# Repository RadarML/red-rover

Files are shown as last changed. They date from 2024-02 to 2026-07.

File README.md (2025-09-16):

# Red Rover: A Multimodal mmWave Radar Spectrum Ecosystem





bear-ified (https://beartype.readthedocs.io)

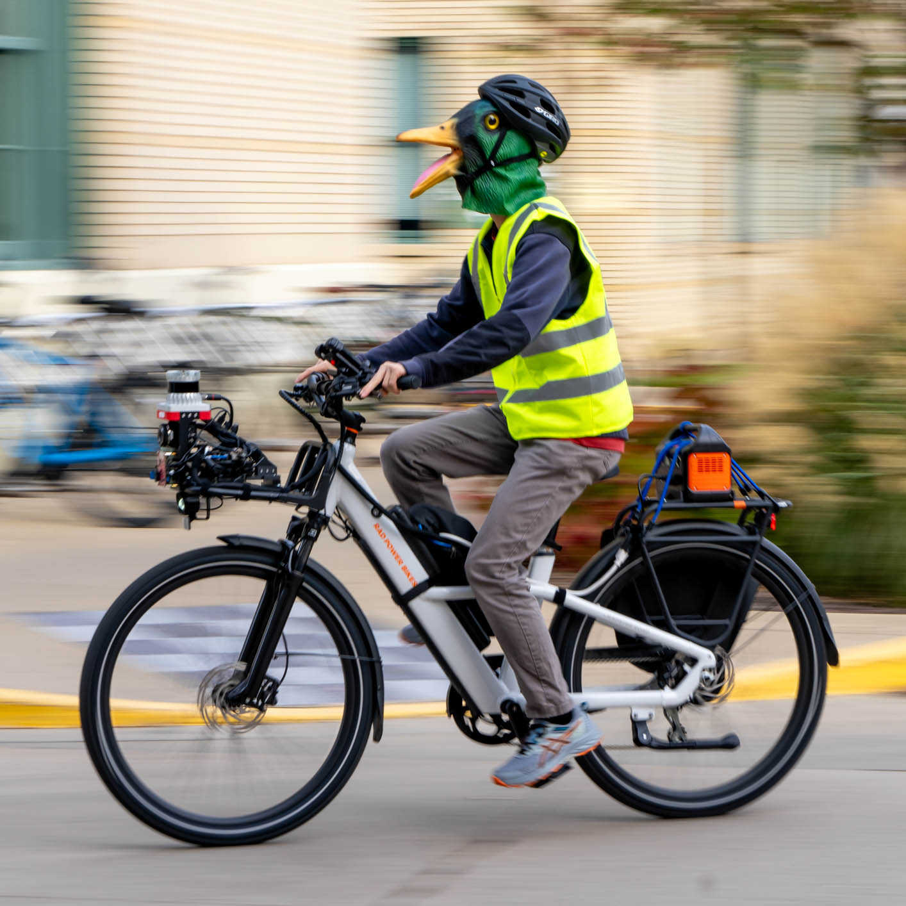
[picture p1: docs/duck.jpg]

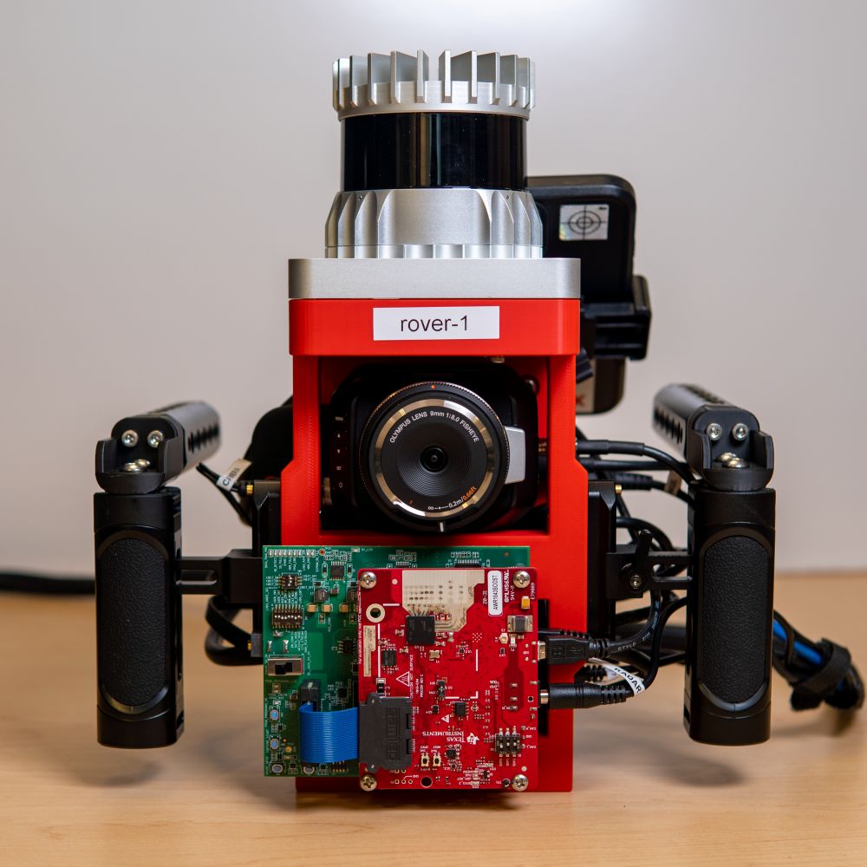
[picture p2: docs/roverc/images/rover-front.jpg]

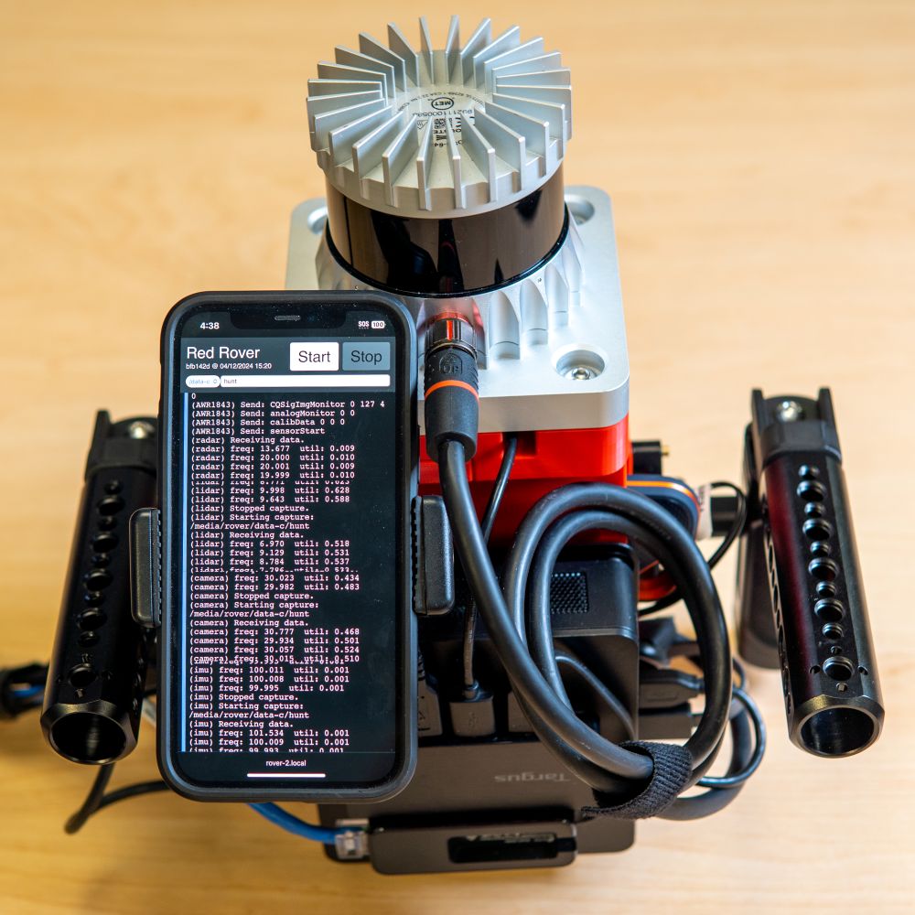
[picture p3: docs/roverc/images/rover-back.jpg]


The **red rover** project is an end-to-end system for collecting, loading, and processing mmWave radar time signal data along with lidar and camera data designed for both [DART](https://wiselabcmu.github.io/dart/)-style reconstruction and [GRT](https://wiselabcmu.github.io/grt/)-style deep learning.

> [!TIP]
> While packaged together as a mono-repo, each module is designed to be able to be installed and used separately. See each module's documentation for requirements and setup instructions.

See our [documentation site](https://radarml.github.io/red-rover/) for more details!

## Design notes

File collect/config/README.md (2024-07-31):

Current configurations (output of `./env/bin/python config/summary.py`):

```
dart.yaml         // DART, indoor
-------------------------------------------
Antenna       2tx x 4rx
Range         4.4cm   x 128 (rmax=5.59m)
Roppler       1.9cm/s x 128 (dmax=1.21m/s)
Throughput    42mbps / 701mbps
Duty cycle    99.8%
Excess ramp   2.100us
```

```
radarhd-b.yaml    // RadarHD, bike-mounted
-------------------------------------------
Antenna       3tx x 4rx
Range         17.5cm   x 256 (rmax=44.74m)
Roppler       23.4cm/s x  64 (dmax=7.49m/s)
Throughput    126mbps / 701mbps
Duty cycle    16.5%
Excess ramp   2.700us
```

```
radarhd-i.yaml    // RadarHD, indoor
-------------------------------------------
Antenna       3tx x 4rx
Range         4.4cm   x 256 (rmax=11.18m)
Roppler       3.8cm/s x  64 (dmax=1.22m/s)
Throughput    126mbps / 701mbps
Duty cycle    99.5%
Excess ramp   2.100us
```

```
radarhd-o.yaml    // RadarHD, outdoor
-------------------------------------------
Antenna       3tx x 4rx
Range         8.7cm   x 256 (rmax=22.37m)
Roppler       3.9cm/s x  64 (dmax=1.24m/s)
Throughput    126mbps / 701mbps
Duty cycle    99.5%
Excess ramp   2.100us
```

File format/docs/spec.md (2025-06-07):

# Data Format Specifications

!!! abstract "TL;DR"

    The `roverd` data format is an extremely simple, flexible, and extendable data storage format based on simple binary containers.

## Design Goals

The rover dataset format, `roverd` is designed to handle data collection and storage for concurrent sensor streams with a fixed dimension, such as camera, lidar, or radar data.

### Seamless Collection & Training

!!! success "Appendable"

    The data format should be easy to append new observations to.

    *By writing files in a simple binary format in a time-synchronous way within each sensor stream, appending data is trivial -- just append data to the file; no metadata updates are required.*

!!! success "Fail-safe"

    If the data collection program or device were to fail during data collection, the amount of lost or corrupted data should be minimized.

    *Since data is simply appended without any summary metadata which needs to be committed when the file is closed, program or device crashes only lose any data which is currently buffered.*

!!! success "Suitable for ML"

    The storage format should facilitate common machine learning access patterns (e.g., random access), so that collected data can immediately be used for training.

    *All data types are designed to facilitate random access right out-of-the-box, without any mandatory preprocessing.*

### Lightweight & Hackable 

!!! success "Readable with common tools"

    The collected data and metadata should be readable with off-the-shelf software (e.g. what ships with a stock linux, windows, or Mac OS distribution) to the greatest extent possible.

    *Data is organized using the native file system, and can be browsed using any file manager. Metadata files are simple `.json` or `.yaml` files, which can be readily viewed or modified with generic text editors.*

!!! success "Extendable"

    It should be easy to use arbitrary file formats, possibly with domain-specific compression techniques.

    *Data channels can specify an arbitrary file format, which is redirected to the appropriate reader or writer.*

!!! success "Simple to implement"

    It should be easy and simple to implement any subset of functionality for operating on datasets.

    *Roverd is incredibly simple, and users only need to implement the parts of the specification that they need.*

## Why Not...

| | Roverd | HDF5 | Numpy | Parquet | 
| --- | --- | ---- | --- | --- |
| Appendable | :white_check_mark: | :white_check_mark: | :x: | :white_check_mark: |
| Fail-safe | :white_check_mark: | :asterisk: | :x: | :asterisk: |
| Suitable for ML | :white_check_mark: | :white_check_mark: | :white_check_mark: | :x: |
| Readable with common tools | :asterisk: | :x: | :asterisk: | :x: |
| Extendable | :white_check_mark: | :x: | :x: | :x: |
| Simple to implement | :white_check_mark: | :x: | :white_check_mark: | :x: |

### HDF5?

HDF5 is [commonly criticized](https://cyrille.rossant.net/moving-away-hdf5/) for its clunkiness: in short, HDF5 is a monster of a standard, and our use cases require maybe 1% of its functionality. By using our own file format, we enable users to view and edit metadata files using common GUI and command line tools (e.g. file managers and text editors), while vastly simplifying the system by using the native file system instead of HDF5's filesystem-within-a-filesystem.

If we were to use HDF5, we would also run into trouble when using domain-specific compression formats, e.g. video:

- If included the video inside the HDF5 file, off-the-shelf video players would not be able to open it.
- Alternatively, we could store the video externally; however, then we would need to implement our own metadata management for these external files and a wrapper to integrate the two, which is almost as much work as spinning a custom dataset format!

### `npz` or `npy`?

NPZ or NPY files cannot be easily appended to, since they require metadata to be written "up front." We also would need to implement a parallel data management system anyways for videos and other domain-specific formats, and would not be able to rely solely on the array naming system in `npz` files.

### Parquet?

Parquet is not suitable for random acess, e.g., in deep learning, since data are compressed together in row groups. While it's theoretically possible to use parquet files with row group size 1, this is not what the format is designed for; accordingly, tooling is also not designed around this use case. Finally, the same domain-specific-format problem also applies,.

## Specifications

### Channel

!!! abstract "Channels"

    A `Channel` (e.g., `iq`, `acc`, `rng`) is a single sequential, homogenous data stream from a sensor.

Each channel is stored as a file, and may be stored in a raw binary format, compressed, or any other format (e.g., `raw`, `lzma`, `mjpeg`).

- Channel names may have file extensions (e.g. `.avi`) if the file format can be interpreted by off-the-shelf programs.
- The "shape" of each channel is described by the constant axes of the data, i.e. the overall array for a channel with `N` observations has shape `(N, *shape)`.
- All data should be stored in little endian.

Channel names cannot be `meta.json` or `ts`.

- ... with exception of the special "timestamp" channel, which should have format `raw` and type `f8` (8-byte double precision float), and contain the epoch time, measured in seconds.

### Sensor

!!! abstract "Sensor"

    A `Sensor` (e.g. `imu`, `lidar`, `radar`, `camera`) is a collection of time-synchronous channels, where sequential entries in each channel correspond to a single series of timestamps.

Sensors are represented by directories, containing one file for each channel.

- Sensor names must not start with an underscore (`_`).
- Sensor directories may contain additional non-channel metadata / sensor intrinsics files other than `meta.json`, e.g. `lidar.json`.

Each sensor directory must have a `meta.json` file, which includes the data type and file format for each sensor channel.

??? quote "Example `meta.json`"

    ```json
    {
        "iq": {
            "format": "raw", "type": "i2", "shape": [64, 3, 4, 512],
            "desc": "Raw I/Q stream."
        },
        "ts": {
            "format": "raw", "type": "f8", "shape": [],
            "description": "Timestamp, in seconds."
        }
    }
    ```
- Data types are specified according to the [numpy size-in-bytes convention](https://numpy.org/doc/stable/reference/arrays.dtypes.html), e.g. `i2` for 2-byte signed integer (`short`, `int16`) or `f8` for 8-byte floating point (`double`, `float64`).

### Dataset

!!! abstract "Dataset"

    A `Dataset` is a directory containing a collection of (likely asynchronous) sensors.

??? quote "Example structure"
    ```
    example/
        _scratch/       # ignored
            ...
        _odom           # virtual sensor
            acc
            avel
            meta.json
            rot
            ts
        camera/         # physical sensor
            meta.json
            ts
            vdeo.avi
        ...
        config.yaml     # dataset metadata
        ...
    ```

Any directories inside the dataset directory containing a `meta.json` file are treated as sensors.

- A `README`, `config.yaml`, or other metadata files can be placed in the root dataset folder if desired.
- Any files which do not contain raw collected data should be placed in directories starting with an underscore (e.g. `_scratch`, `_out`, `_radad`).
- Processed output files placed in a directory along with a valid `meta.json` are interpreted as "virtual" sensors, e.g. decompressed or processed data.

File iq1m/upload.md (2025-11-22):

## Upload

!!! info

    We currently have a 5TB bucket provisioned in OSN. To check the current utilization:
    ```sh
    rclone size osn-rw:/cmu-wiselab-iq1m
    ```   
    
Create a read/write configuration:

```toml
[osn-rw]
type = s3
provider = Ceph
access_key_id = # ask tianshu or get this from coldfront
secret_access_key =   # ...
endpoint = https://uri.osn.mghpcc.org
no_check_bucket = true
```

Then, upload with
```sh
rclone sync /data osn-rw:/cmu-wiselab-iq1m/data --include-from iq1m/upload.txt -v
```

The original instructions from OSN can also be found [here](https://openstoragenetwork.github.io/docs/dataset-access/rclone/).

??? quote "Uploaded Files"

    `iq1m.txt` includes the following:
    ```
    --8<-- "iq1m/upload.txt"
    ```

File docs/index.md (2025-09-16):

# **Red Rover**: A Multimodal mmWave Radar Spectrum Ecosystem





bear-ified (https://beartype.readthedocs.io)

<div style="display: grid; grid-template-columns: 1fr 1fr; gap: 5px;">
    
    
</div>

The **red rover**[^1] project is an end-to-end system for collecting, loading, and processing mmWave radar time signal data along with lidar and camera data designed for both [DART](https://wiselabcmu.github.io/dart/)-style reconstruction and [GRT](https://wiselabcmu.github.io/grt/)-style deep learning.

!!! info

    While packaged together as a mono-repo, each module is designed to be able to be installed and used separately. See each module's documentation for requirements and setup instructions.

[^1]: Red Rover is an [evolved](https://en.wikipedia.org/wiki/Pok%C3%A9mon_Red,_Blue,_and_Yellow) version of our previous data collection system, [rover](https://github.com/wiseLabCMU/rover), which happens to be red.

## Red Rover

<div class="grid cards" markdown>

- :material-golf-cart: [`roverc`](./roverc/index.md)

    ---

    radar + lidar + camera + imu data collection system

- :material-database-cog: [`roverd`](./roverd/index.md)

    ---

    efficient recording and storage format with an adl-compliant dataloader

- :material-factory: [`roverp`](./roverp/index.md)

    ---

    data processing and visualization tooling for red rover

- :material-database: [`i/q-1m`](./iq1m/index.md)

    ---

    one million i/q frames across indoor, outdoor, and bike-mounted settings

</div>

## See Also

<div class="grid cards" markdown>

- :material-cube-outline: [`abstract_dataloader`](https://radarml.github.io/abstract-dataloader/)

    ---

    abstract interface for composable dataloaders and preprocessing pipelines

- :material-antenna: [`xwr`](https://radarml.github.io/xwr/)

    ---

    python interface for collecting raw time signal data from TI mmWave radars

- :octicons-ai-model-16: [`nrdk`](https://radarml.github.io/nrdk/)

    ---

    neural radar development kit for deep learning on multimodal radar data

- :fontawesome-solid-hexagon-nodes: [`grt`](https://wiselabcmu.github.io/grt/)

    --- 

    *our latest work, GRT: Towards Foundational Models for Single-Chip Radar*

- :dart: [`dart`](https://wiselabcmu.github.io/dart/)

    ---

    *our prior work, DART: Implicit Doppler Tomography for Radar Novel View Synthesis*

- :material-video-wireless-outline: [`rover`](https://github.com/wiseLabCMU/rover)

    ---

    *our previous data collection platform for radar time signal*

</div>

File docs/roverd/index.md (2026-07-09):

# **roverd**: data interface




bear-ified (https://beartype.readthedocs.io)

!!! abstract "TL;DR"

    - The [`roverd` data format](#specifications) is an extremely simple, flexible, and extendable data storage format based on simple binary containers.
    - The [`roverd` API](./api.md) provides an [abstract dataloader-compliant](https://radarml.github.io/abstract-dataloader/) data loading implementation.

You can install the `roverd` library from github:
```sh
pip install "roverd[video]@git+ssh://git@github.com/RadarML/red-rover.git#subdirectory=format"
```
In addition to the `roverd` package, this also installs the [`roverd info` and `roverd validate` CLI tools](./cli.md).

!!! info "Extras"

    - `roverd[video]` (`opencv-python-headless`): read camera data.

## Design Goals

The rover dataset format, `roverd` is designed to handle data collection and storage for concurrent sensor streams with a fixed dimension, such as camera, lidar, or radar data.

### Seamless Collection & Training

!!! success "Appendable"

    The data format should be easy to append new observations to.

    *By writing files in a simple binary format in a time-synchronous way within each sensor stream, appending data is trivial -- just append data to the file; no metadata updates are required.*

!!! success "Fail-safe"

    If the data collection program or device were to fail during data collection, the amount of lost or corrupted data should be minimized.

    *Since data is simply appended without any summary metadata which needs to be committed when the file is closed, program or device crashes only lose any data which is currently buffered.*

!!! success "Suitable for ML"

    The storage format should facilitate common machine learning access patterns (e.g., random access), so that collected data can immediately be used for training.

    *All data types are designed to facilitate random access right out-of-the-box, without any mandatory preprocessing.*

### Lightweight & Hackable 

!!! success "Readable with common tools"

    The collected data and metadata should be readable with off-the-shelf software (e.g. what ships with a stock linux, windows, or Mac OS distribution) to the greatest extent possible.

    *Data is organized using the native file system, and can be browsed using any file manager. Metadata files are simple `.json` or `.yaml` files, which can be readily viewed or modified with generic text editors.*

!!! success "Extendable"

    It should be easy to use arbitrary file formats, possibly with domain-specific compression techniques.

    *Data channels can specify an arbitrary file format, which is redirected to the appropriate reader or writer.*

!!! success "Simple to implement"

    It should be easy and simple to implement any subset of functionality for operating on datasets.

    *Roverd is incredibly simple, and users only need to implement the parts of the specification that they need.*

## Why Not...

| | Roverd | HDF5 | Numpy | Parquet | 
| --- | --- | ---- | --- | --- |
| Appendable | :white_check_mark: | :white_check_mark: | :x: | :white_check_mark: |
| Fail-safe | :white_check_mark: | :asterisk: | :x: | :asterisk: |
| Suitable for ML | :white_check_mark: | :white_check_mark: | :white_check_mark: | :x: |
| Readable with common tools | :asterisk: | :x: | :asterisk: | :x: |
| Extendable | :white_check_mark: | :x: | :x: | :x: |
| Simple to implement | :white_check_mark: | :x: | :white_check_mark: | :x: |

### HDF5?

HDF5 is [commonly criticized](https://cyrille.rossant.net/moving-away-hdf5/) for its clunkiness: in short, HDF5 is a monster of a standard, and our use cases require maybe 1% of its functionality. By using our own file format, we enable users to view and edit metadata files using common GUI and command line tools (e.g. file managers and text editors), while vastly simplifying the system by using the native file system instead of HDF5's filesystem-within-a-filesystem.

If we were to use HDF5, we would also run into trouble when using domain-specific compression formats, e.g. video:

- If included the video inside the HDF5 file, off-the-shelf video players would not be able to open it.
- Alternatively, we could store the video externally; however, then we would need to implement our own metadata management for these external files and a wrapper to integrate the two, which is almost as much work as spinning a custom dataset format!

### `npz` or `npy`?

NPZ or NPY files cannot be easily appended to, since they require metadata to be written "up front." We also would need to implement a parallel data management system anyways for videos and other domain-specific formats, and would not be able to rely solely on the array naming system in `npz` files.

### Parquet?

Parquet is not suitable for random acess, e.g., in deep learning, since data are compressed together in row groups. While it's theoretically possible to use parquet files with row group size 1, this is not what the format is designed for; accordingly, tooling is also not designed around this use case. Finally, the same domain-specific-format problem also applies,.

## Specifications

### Channel

!!! abstract "Channels"

    A `Channel` (e.g., `iq`, `acc`, `rng`) is a single sequential, homogenous data stream from a sensor.

Each channel is stored as a file, and may be stored in a raw binary format, compressed, or any other format (e.g., `raw`, `lzma`, `mjpeg`).

!!! info

    See the [channels](./channels.md) documentation for specifications about each supported format.

- Channel names may have file extensions (e.g. `.avi`) if the file format can be interpreted by off-the-shelf programs.
- The "shape" of each channel is described by the constant axes of the data, i.e. the overall array for a channel with `N` observations has shape `(N, *shape)`.
- All data should be stored in little endian.

Channel names cannot be `meta.json` or `ts`.

- ... with exception of the special "timestamp" channel, which should have format `raw` and type `f8` (8-byte double precision float), and contain the epoch time, measured in seconds.

### Sensor

!!! abstract "Sensor"

    A `Sensor` (e.g. `imu`, `lidar`, `radar`, `camera`) is a collection of time-synchronous channels, where sequential entries in each channel correspond to a single series of timestamps.

Sensors are represented by directories, containing one file for each channel.

- Sensor names must not start with an underscore (`_`).
- Sensor directories may contain additional non-channel metadata / sensor intrinsics files other than `meta.json`, e.g. `lidar.json`.

Each sensor directory must have a `meta.json` file, which includes the data type and file format for each sensor channel.

??? quote "Example `meta.json`"

    ```json
    {
        "iq": {
            "format": "raw", "type": "i2", "shape": [64, 3, 4, 512],
            "desc": "Raw I/Q stream."
        },
        "ts": {
            "format": "raw", "type": "f8", "shape": [],
            "description": "Timestamp, in seconds."
        }
    }
    ```
- Data types are specified according to the [numpy size-in-bytes convention](https://numpy.org/doc/stable/reference/arrays.dtypes.html), e.g. `i2` for 2-byte signed integer (`short`, `int16`) or `f8` for 8-byte floating point (`double`, `float64`).

### Dataset

!!! abstract "Dataset"

    A `Dataset` is a directory containing a collection of (likely asynchronous) sensors.

??? quote "Example structure"
    ```
    example/
        _scratch/       # ignored
            ...
        _odom           # virtual sensor
            acc
            avel
            meta.json
            rot
            ts
        camera/         # physical sensor
            meta.json
            ts
            vdeo.avi
        ...
        config.yaml     # dataset metadata
        ...
    ```

Any directories inside the dataset directory containing a `meta.json` file are treated as sensors.

- A `README`, `config.yaml`, or other metadata files can be placed in the root dataset folder if desired.
- Any files which do not contain raw collected data should be placed in directories starting with an underscore (e.g. `_scratch`, `_out`, `_radad`).
- Processed output files placed in a directory along with a valid `meta.json` are interpreted as "virtual" sensors, e.g. decompressed or processed data.

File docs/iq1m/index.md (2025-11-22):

# I/Q-1M: one million i/q frames




<div style="display: grid; grid-template-columns: repeat(auto-fit, minmax(200px, 1fr)); gap: 5px;">
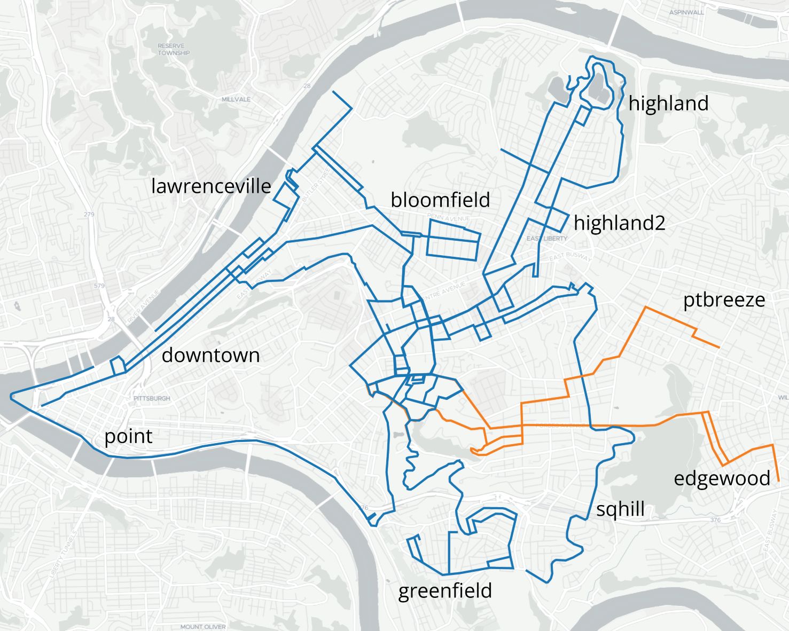
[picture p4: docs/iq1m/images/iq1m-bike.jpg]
IQ1M Bike
    
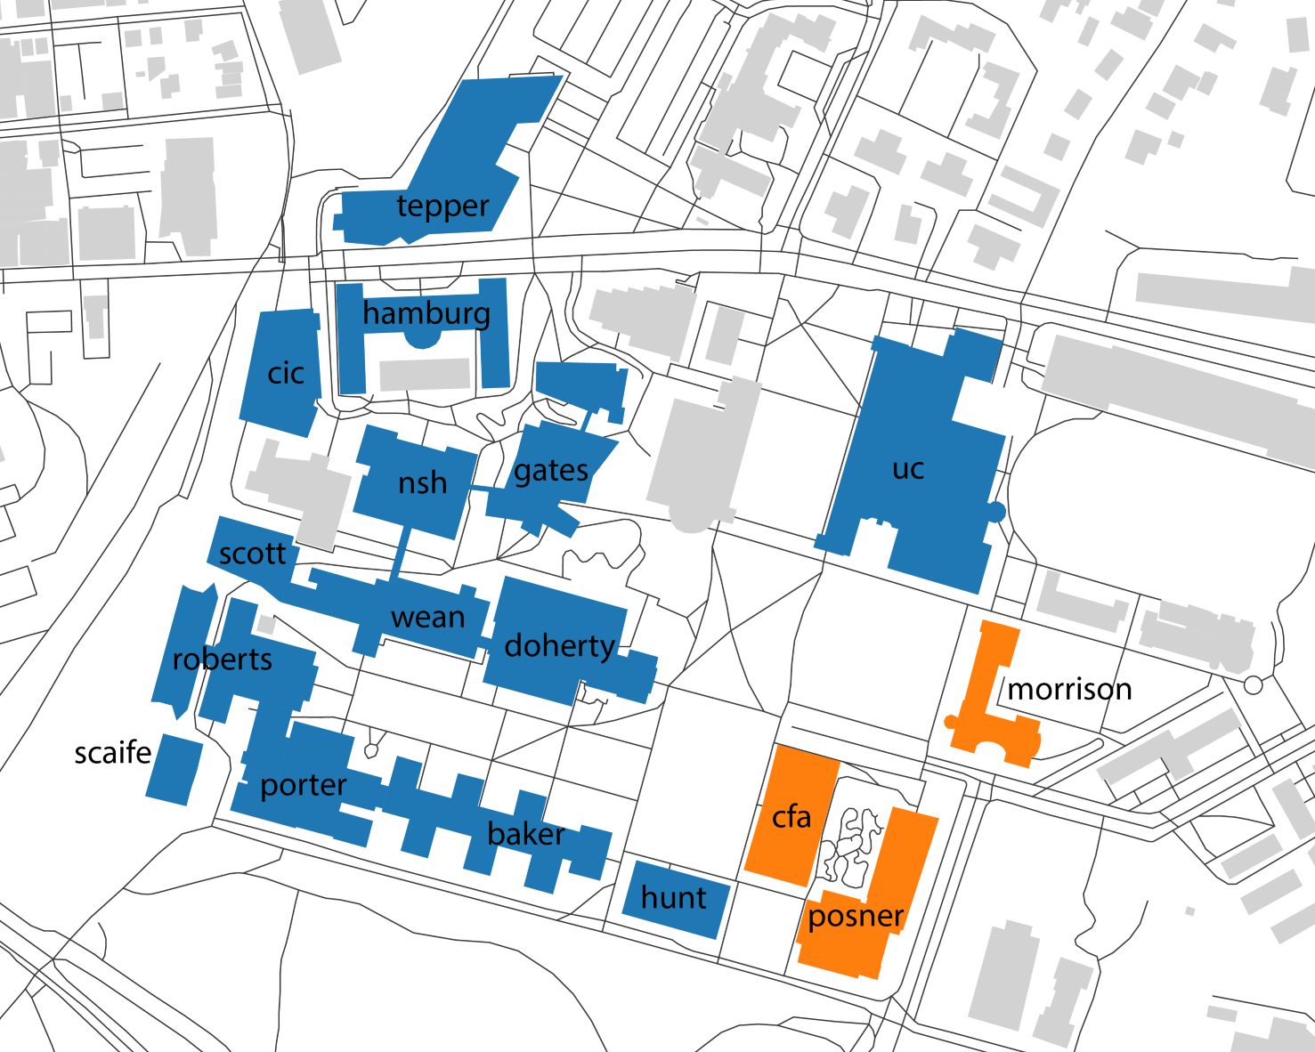
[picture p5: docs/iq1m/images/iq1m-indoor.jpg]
IQ1M Indoor
    
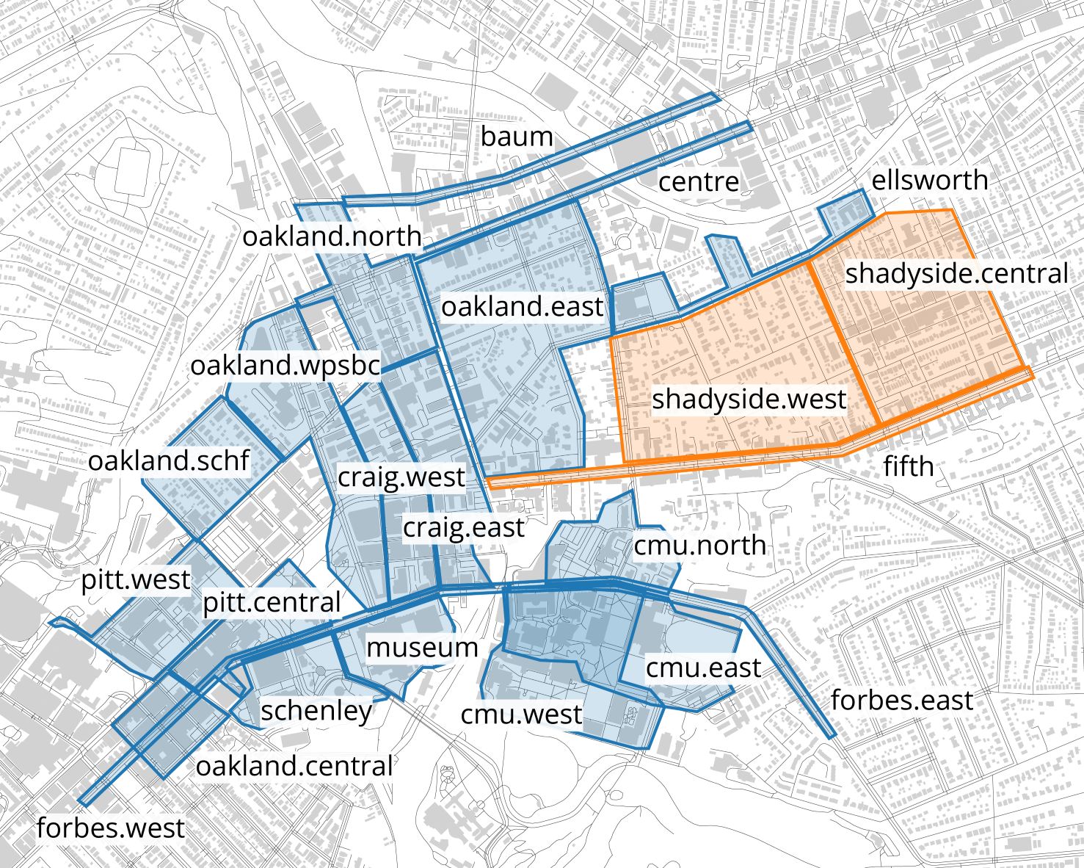
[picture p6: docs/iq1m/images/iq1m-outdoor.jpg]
IQ1M Outdoor
    
</div>

## Overview

The I/Q-1M dataset consists of 1M radar-lidar-camera samples[^1] over 29 hours across indoor, outdoor, and bike-mounted settings, each with a mobile observer:

- `indoor`: inside buildings at a slow to moderate walking pace, visiting multiple floors and areas within each.
- `outdoor`: neighborhoods ranging from single family detached to high density commercial zoning at a moderate to fast walking pace.
- `bike`: bike rides in different directions from a set starting point with a moderate biking pace.

Our dataset distribution also includes [GRT model](https://wiselabcmu.github.io/grt/) checkpoints pre-trained for each objective (3D occupancy, 2D occupancy, semantic segmentation, and ego-motion).

!!! tip

    See [our paper](https://arxiv.org/pdf/2509.12482?) for more details about the dataset. Make sure to download the arxiv version to see the attached (and linked) appendix!

[^1]: The radar was collected at 20Hz, the Lidar at 10Hz, and the camera at 30Hz; as such, Lidar is limiting sensor to arrive at our 1M sample count.

| Setting | Size | Length | Average Speed | Max Doppler | Max Range |
|---|---|---|---|---|---|
| `indoor` | 310k | 8.9h | 1.0m/s | 1.2m/s | 11.2m |
| `outdoor` | 372k | 10.7h | 1.4m/s | 1.8m/s | 22.4m |
| `bike` | 333k | 9.3h | 5.4m/s | 8.0m/s | 22.4m |

## Index of Files

!!! tip

    See the [roverd](../roverd/index.md) documentation for details about the data format.

```
{sequence}
 ┣ 📂_camera
 ┃ ┣ 📜meta.json
 ┃ ┣ 📜pose.npz             # interpolated cartographer poses with camera timestamps
 ┃ ┣ 📜segment              # lzma-compressed semantic segmentation class maps
 ┃ ┣ 📜segment_i            # byte offsets
 ┃ ┣ 📜ts                   # camera timestamps (same as camera/ts)
 ┃ ┗ 📜video.avi            # anonymized video (MJPEG)
 ┣ 📂_lidar
 ┃ ┗ 📜pose.npz             # cartographer poses with lidar timestamps
 ┣ 📂_radar
 ┃ ┗ 📜pose.npz             # cartographer poses with radar timestamps
 ┣ 📂_slam
 ┃ ┗ 📜trajectory.csv       # raw cartographer output
 ┣ 📂camera
 ┃ ┣ 📜meta.json
 ┃ ┗ 📜ts                   # camera timestamps (30Hz)
 ┣ 📂imu
 ┃ ┣ 📜acc                  # linear acceleration
 ┃ ┣ 📜avel                 # angular velocity
 ┃ ┣ 📜meta.json
 ┃ ┣ 📜rot                  # rotation
 ┃ ┗ 📜ts                   # IMU timestamps (100Hz)
 ┣ 📂lidar
 ┃ ┣ 📜lidar.json
 ┃ ┣ 📜meta.json
 ┃ ┣ 📜nir                  # lzma-compressed near-infrared image
 ┃ ┣ 📜nir_i                # byte offsets
 ┃ ┣ 📜rfl                  # lzma-compressed IR reflectance
 ┃ ┣ 📜rfl_i                # byte offsets
 ┃ ┣ 📜rng                  # lzma-compressed beam-time depth map
 ┃ ┣ 📜rng_i                # byte offsets
 ┃ ┗ 📜ts                   # lidar timestamps (10Hz)
 ┣ 📂radar
 ┃ ┣ 📜iq                   # raw complex time signal (IIQQ format)
 ┃ ┣ 📜meta.json
 ┃ ┣ 📜radar.json           # radar intrinsics
 ┃ ┣ 📜ts                   # radar timestamps (20Hz)
 ┃ ┗ 📜valid                # whether frames contain zero-filled dropped packets
 ┗ 📜config.yaml            # original data collection configuration
```

??? info "Semantic Segmentation Classes"

    | 0 | 1 | 2 | 3 |
    |---|---|---|---|
    | flat | nature | sky | structure |

    | 4 | 5 | 6 | 7 |
    |---|---|---|---|
    | ceiling | object | person | vehicle |

    For full details about the class definitions, see the [class mapping](https://github.com/RadarML/red-rover/blob/main/processing/models/segformer-b5-finetuned-ade-640-640/classes.yaml) and [original ADE20k dataset](https://groups.csail.mit.edu/vision/datasets/ADE20K/).

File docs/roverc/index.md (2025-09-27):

# **roverc**: data collection system




bear-ified (https://beartype.readthedocs.io)

<div class="grid" markdown>

Front

Back

</div>

<div class="grid cards" markdown>

- **Already have a `red-rover` system?**

    ---

    :material-arrow-right: See the [usage instructions](usage.md), and read the [data collection tips](tips.md).

- **Trying to set up a `red-rover` system?**

    ---

    :material-arrow-right: Follow the [assembly guide](assembly.md) and the [setup guide](setup.md).

- **Considering building a `red-rover` system?**

    ---

    :material-arrow-right: See the [bill of materials](assembly.md).

- **Just want to use the data?**

    ---

    :material-arrow-right: Skip forward to the [data format documentation](../roverd/index.md).

</div>

## Mechanical Design

**Core Platform**: `red-rover` is built around a laterally aligned lidar, radar, and camera on a handheld platform.

- [TI AWR1843Boost](https://www.ti.com/tool/AWR1843BOOST) + [DCA1000EVM](https://www.ti.com/tool/DCA1000EVM): radar and capture card commonly used for academic radar research; see the [xwr documentation](https://radarml.github.io/xwr/setup/#awr1843boost).

- [Ouster OS0-32/64/128](https://ouster.com/products/hardware/os0-lidar-sensor) wide field of view (360x90 degree) lidar: provides a good field of view, even in tight and cluttered indoor spaces.

    !!! failure

        The range of the OS0 does suffer considerably in outdoor scenarios; in practice, it only achieves ~20-25m maximum effective range. As such, we limit the maximum range of our radar to 22m. Iterations on `red-rover` should consider upgrading to an OS1 or OS2.

    !!! info

        We also include an additional [XSens MTi-3](https://shop.movella.com/us/product-lines/sensor-modules/products/mti-3-ahrs-development-kit) (hidden beneath the Lidar), which we use for SLAM; we find that this provides better accuracy than the Lidar's onboard IMU due to noise caused by the Lidar rotation, especially when it is running in a faster 20Hz mode.

- [Black Magic Micro Studio Camera](https://www.bhphotovideo.com/c/product/1787638-REG/blackmagic_design_micro_studio_camera_4k.html) + [Olympus Fisheye Body Cap Lens](https://www.bhphotovideo.com/c/product/1026132-REG/olympus_v325040bw000_bcl_0980_fisheye_body_cap.html): the BMMSC can be purchased for around the same cost as a similar computer vision camera, while having a substantially larger sensor and better image quality. The lens does not have the greatest image quality, but f/8 is reasonable for our "zone-focus" use case, and still looks better than a typical computer vision lens.

**Design Features**:

- The `red-rover` platform includes two side handles, each of which has an upper and lower part. This is designed to facilitate holding the rig at a variety of poses, e.g., above the head, at waist level, or below the waist.
- Both handles are easily adjustable and detachable to facilitate easy transport.
- The power supply is located on a backpack-carried power pack to reduce the weight of the handheld portion. However, we opted not to place the data collection computer in the backpack, since this avoids needing to run many data cables to the backpack in addition to the many power cables currently carried by the umbilical.

## Software Design

!!! question "Why not ROS?"

    ROS does have substantial infrastructure as a whole; however:

    - There are no existing ROS nodes for handling radar data.
    - ROS has issues with tracking accurate timestamps.
    - Off-the-shelf ROS nodes, e.g., for collecting lidar data, tend to be very inefficient. For example, our custom lidar recording implementation results in >10x disk savings over recording ros bags of lidar point clouds.
    - ROS tends to have very specific software requirements, that make it difficult to deploy in already-existing systems.

    Finally, the `red-rover` data collection system is really not that complicated, and not overly burdensome to build from scratch. Thus, while we did use ROS in our previous system, [rover](https://github.com/wiseLabCMU/rover), we opted not to use ROS for `red-rover`.

The `roverc` recording software is based on a client-server architecture:

- Each sensor is independently and asynchronously recorded by a separate process running a python data collection program.

    !!! info

        This is accomplished by our [standalone python implementation](https://radarml.github.io/xwr/) of the TI radar and capture card interfaces, which replaces the windows-only mmWave studio software which is typically used for radar data collection.

- These processes communicate via unix domain sockets to a control server by sending output logs to the server, and receiving commands.
- The control server also exposes a web server (via a flask app) which hosts a GUI which can be used to start/stop data collection, set metadata, and view output logs.

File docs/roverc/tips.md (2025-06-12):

# Collecting Good Data

## GRT

!!! success "Avoid low / stationary speeds."

    Low speeds lead to reduced doppler information.

!!! success "Keep a level roll angle."

    When used for classic 2D occupancy training, the Bird's Eye View (BEV) is derived from the horizontal plane of the sensor. Maintain a level roll angle where this plane is aligned with the floor (so the BEV matches what a floor plan would look like).

!!! success "Keep a consistent velocity."

    Provide consistent doppler to the model.

!!! success "Clearly separate movement patterns."

    Ensure balance between different movement patterns in the train/val/test splits.

    As a suggested split for the handheld case, record one trace when walking forward (velocity aligned with sensor) and another when walking sideways (velocity perpendicular with sensor). Note that backwards movement can be obtained from forwards movement using data augmentation (reverse doppler axis), while left and right-handed lateral movement can be similarly obtained (reverse doppler and azimuth axes).

!!! failure "Do not enter elevators."

    This is literally the kidnapped robot problem, not to mention that elevators are kind of boring as far as data goes.

!!! success "Maintain depth diversity when possible."

    Try to make sure each frame has a mix of close and far objects when possible. In particular, avoid pointing the sensor directly at a wall from a close distance.

## Cartographer

!!! failure "Avoid rapid rotation and acceleration."

    We observe that Cartographer tends to perform poorly when the rig rotates rapidly. Keep in mind that velocity differentiates the estimated pose, so is an order of magnitude more sensitive to any error.

    In DART configuration, also note that the Lidar runs at 20Hz, while the radar requires the trajectory to be resampled to 10Hz, which is at the Nyquist limit. Combined with the high velocity jitter (at least in the velocity domain) which we observe, possibly due to loop closures which do not preserve second order pose continuity, aggressive smoothing is typically required.

!!! failure "Avoid vertical jitter."

    Since the Lidar is mostly planar, estimating the vertical position of the rig is relatively imprecise. The typical solution to this problem is to use two Lidars, one of which is downwards-facing, but we do not want to require two Lidars on the rig.

!!! success "Keep features visible."

    Stay conscious of which portions of the Lidar your body is blocking; this can lead to loop closure failures when traversing tight spaces, especially relatively narrow restrictions combined with occlusions and a tight turn. Consider holding the radar to your side or above your head to maintain two-way visibility.

!!! success "Keep a low speed."

    The scan rate of the Lidar is limited, so fast movement speeds will reduce velocity estimation accuracy. The 1m/s target speed for the DART config seems to work well when combined with 20Hz Lidar scans.

## DART

!!! success "Keep your velocity close to, but under, the maximum doppler."

    Sections of the trace which exceed the maximum doppler must be discarded due to doppler ambiguity (i.e. "wrapping"). Sections of the trace which reduce below the minimum doppler (typically `0.2 * max_doppler`) are discarded due to excessively wide / degenerate doppler bins.

### Novel View Synthesis

!!! failure "Avoid Excessively Cluttered Scenes."

    Clutter cannot be effectively resolved by our radar, and end up being stochastically averaged (e.g. as blurry regions in synthesized frames).

!!! success "Keep the validation set within domain."

    All regions covered by the validation step (typically the last 20% of the trace) should be within domain. As a suggested pattern, cover above/below chest/waist level during training (in addition to pointing in-plane), then keep the radar in-plane for validation.

!!! success "Prefer inside-out scanning."

    Since the radar has a 180 degree FOV, the vast majority of the radar images will always cover the background of a scene. As such, any single object within the scene will always be a negligible contributor to NVS performance.

!!! success "Emphasize occlusion."

    Any baseline method will work fine in an empty box. Try to find scenes with prominent occlusions at the room scale, e.g. two adjacent rooms or spaces with a dividing wall.

### Tomography

!!! success "Capture multiple viewing angles."

    Some specular surfaces may not show up unless viewed from specific angles. Cover multiple angles, including at multiple heights, to capture these.

    As a suggested pattern, try waist/chest level, above the head, and as low as possible.

!!! failure "Avoid downwards-facing views."

    Floors are often highly specular and highly reflective. Too much emphasis on downwards-facing views may lead to the floor being a dominating feature of the scene. For floorplans, XR tomography visualizations, and other "pretty picture"-type datasets, consider de-emphasizing the floor.

!!! success "Prefer outside-in scanning."

    Outside-in scenes give the opportunity to capture many different angles of all surfaces, giving better tomography quality when the background is cropped out.

!!! success "Maximize the scene size."

    Errors in DART appear to be size-invariant (e.g. constant spatial resolution error). Larger scenes will therefore have a higher relative/perceived spatial resolution.

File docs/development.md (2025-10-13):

# Development

While each red-rover module is intended to be installed and used independently, we provide a single development environment based on a shared `pyproject.toml`.

!!! warning

    While `roverc` (`red-rover/collect`) is nominally a part of the development environment (e.g., for documentation), it is not actually fully installed in the main environment. Developing `roverc` should use an actual physical data collection system, while the main environment can be used on any linux system.

## Setup

Assuming `uv` is [installed](https://docs.astral.sh/uv/getting-started/installation/), you can install all dependencies with `uv sync --all-extras` in `./red-rover`. This installs the documentation stack, testing / linting tools, and the `roverd: red-rover/format` and `roverp: red-rover/processing` modules as editable (i.e., `pip install -e`) links.

We also use [pre-commit hooks](https://pre-commit.com/); please install these with `uv run pre-commit install`.

!!! info

    You can also manually trigger the pre-commit hooks with `uv run pre-commit run`.

## Documentation

`red-rover` has a single documentation site using `mkdocs` / `mkdocs-material` / `mkdocstrings-python`. To build for development:

```sh
uv run --extra docs mkdocs serve
```

!!! info

    The documentation site is automatically built and deployed by GitHub Actions on push to `main`.

## Testing

Currently, only `roverd` comes with unit tests. Run with
```sh
export ROVERD_TEST_TRACE=/data/roverd/test-trace
uv run --all-extras pytest -ra --cov --cov-report=html --cov-report=term
```
where `ROVERD_TEST_TRACE` should point to a sample data trace with at least 0.5s of valid data across all modalities.

!!! tip

    Serve a live version of the code coverage report using
    ```sh
    uv run python -m http.server 8001 -d ./htmlcov
    ```

## Version Control

`red-rover` is currently managed as a mono-repo, with the three components sharing the same version (which is tagged at the repository level as well). When making changes, please remember to update the version in `pyproject.toml` in each subdirectory.

!!! danger "Regenerate `uv.lock` after Version Bumps"

    Since the monorepo root `pyproject.toml` references each submodule, you must regenerate the root `uv.lock` file after changing versions in any submodule!

    To regenerate and update packages, run
    ```sh
    uv sync --all-extras --upgrade
    ```

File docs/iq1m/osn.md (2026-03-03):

# Download

!!! abstract

    The preferred download method is via the [Open Storage Network](https://openstoragenetwork.github.io/) (OSN), which is a NSF-funded distributed data sharing and transfer service based on S3 buckets. We currently have a storage allocation on OSN which we are trialing to distribute I/Q-1M.

## Get Access Keys

The I/Q-1M dataset is fully open-source and permissively licensed, and does not include any usage restrictions. To help us track usage statistics &mdash; and better target and motivate future datasets and extensions &mdash; we do ask that you fill out [this short questionnaire](https://docs.google.com/forms/d/e/1FAIpQLSeB3x0Ax-OcuEJZW69Eut-Sqj4i4owa6B40BDg16uPfnRwFbg/viewform?usp=dialog) to get the access keys for our dataset.

## Set Up `rclone`

The best way to interact with OSN is through [rclone](https://rclone.org/docs/).

After installing `sudo apt-get install rclone`, you will need to create a configuration with our bucket information:

- Find the config file name using `rclone config file`.

    !!! info
        
        The config path should be something like `~/.config/rclone/rclone.config` i.e., `/home/<user>/.config/rclone/rclone.config`.

- Add the following to the file (create the file if it doesn't already exist):

    ```toml
    [osn-ro]
    type = s3
    provider = Ceph
    access_key_id =  # ...
    secret_access_key =   # ...
    endpoint = https://uri.osn.mghpcc.org
    no_check_bucket = true
    ```

??? info "Test the configuration"

    To test this configuration:

    === "List files"

        ```sh
        $ rclone lsd osn-ro:/cmu-wiselab-iq1m
                0 2025-06-25 16:24:51        -1 data
        ```

        `lsd` lists all directories. You can also use:

        - `rclone ls`: list all files, recursively
        - `rclone ls --max-depth 1`: list only files in the specified folder

    === "Download a sample file"

        ```sh
        rclone copy osn-ro:/cmu-wiselab-iq1m/data/bike/bloomfield.back/config.yaml .
        ```

## Download from OSN

To download the full dataset (3.2TB / 2.9TiB), use:
```sh
rclone sync osn-ro:/cmu-wiselab-iq1m/data ./iq1m -v
```

You can also find our pre-trained model checkpoints in the same bucket:
```sh
rclone sync osn-ro:/cmu-wiselab-iq1m/checkpoints ./iq1m-checkpoints -v
```

??? quote "Checkpoints"

    The following checkpoints are currently available:
    ```
    $ rclone lsd osn-ro:/cmu-wiselab-iq1m/checkpoints
           0 2025-11-22 12:22:46        -1 base     # base model - 3D occupancy
           0 2025-11-22 12:22:46        -1 occ2d    # fine-tune - 2D occupancy
           0 2025-11-22 12:22:46        -1 semseg   # fine-tune - semantic segmentation
           0 2025-11-22 12:22:46        -1 vel      # fine-tune - ego-motion
    ```

!!! tip

    When using `rclone sync`, you can stop (interrupt with ctrl+C) and resume downloading at any time.

!!! warning "Symlink Videos"

    The videos distributed via OSN have been anonymized to blur out faces; you can symlink these in place of the raw videos:
    ```sh
    for i in `uv run roverd list /path/to/dataset`; do
        ln -s /path/to/dataset/$i/_camera/video.avi /path/to/dataset/$i/camera/video.avi;
    done
    ```

??? info "Download Traces Individually"

    You can also download each setting or trace separately:
    ```sh
    rclone sync osn-ro:/cmu-wiselab-iq1m/data/indoor ./iq1m/indoor -v
    rclone sync osn-ro:/cmu-wiselab-iq1m/data/indoor/baker ./iq1m/indoor/baker -v
    rclone sync osn-ro:/cmu-wiselab-iq1m/data/indoor/baker/baker.1.fwd ./iq1m/indoor/baker/baker.1.fwd -v
    ```

??? info "Exclude Unneeded Files"

    You can exclude certain files (e.g., lidar reflectance / NIR) using
    ```sh
    rclone sync osn-ro:/cmu-wiselab-iq1m/data ./iq1m -v --exclude */lidar/rfl */lidar/nir
    ```

    See the `rclone sync` [documentation](https://rclone.org/commands/rclone_sync) for more details and other options.

## FTP Fallback

If you are unable to download the dataset via OSN, we have set up a "fallback" FTP server which also hosts a copy of the dataset.

!!! warning

    This FTP server is hosted in our lab, and has limited resources compared to OSN; to avoid interfering with other traffic, the server is also rate-limited to 100Mbps. **Please only use this option if OSN is down or otherwise inaccessible.**

You can download files from the FTP server using any standard FTP client, e.g., [FileZilla](https://filezilla-project.org/).

| URL | Port |
|-----|---|
| arena-gw.lan.cmu.edu | 37285 |

!!! warning

    The FTP server address and port are subject to change, and our lab network is explicitly not a high-availability service!

## Verify Files

After downloading the dataset, you may wish to verify the integrity of the files by comparing checksums.

!!! info

    You can find the reference checksum files in the [red-rover repository](https://github.com/RadarML/red-rover/blob/main/iq1m/checksums.tar.gz). See [`roverd checksum`](../roverd/cli.md) for more details about how these checksums are computed and formatted; the format should be fairly self-explanatory once you `untar` the files.

Assuming that you've [installed roverd](../roverd/index.md) into your environment:

1. Calculate checksums on your downloaded copy:

    ```sh
    for i in `roverd list /path/to/downloaded/iq1m`; do
        uv run roverd checksum /path/to/downloaded/iq1m/$i /path/to/checksums/output/$i;
    done
    ```

2. Compare the calculated checksums against the reference checksums:

    ```sh
    for i in `roverd list /path/to/downloaded/iq1m`; do
        uv run roverd checksum /path/to/original/checksums/$i /path/to/checksums/output/$i;
    done
    ```

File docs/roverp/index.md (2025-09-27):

# **roverp**: data processing




bear-ified (https://beartype.readthedocs.io)

The data processing tooling for `red-rover` includes some library components, a number of CLI tools, and a makefile for managing a dockerized cartographer SLAM pipeline.

| Tool | Description | Required Extras |
| ---- | --- | --- |
| [`roverp anonymize`](./cli.md#roverp-anonymize) | Anonymize camera data by blurring faces. | `anonymize` |
| [`roverp sensorpose`](./cli.md#roverp-sensorpose) | Get interpolated poses for a specific sensor from a cartographer output. | |
| [`roverp report`](./cli.md#roverp-report) | Generate a "speed report" of a dataset. | |
| [`roverp segment`](./cli.md#roverp-segment) | Run semantic segmentation on collected video data. | `segment` |
| [`make trajectory`](./docker.md) | Compute poses using cartographer. |
| [`make lidar`](./docker.md) | Compute poses and output globally-aligned point clouds. |
| [`make info`](./docker.md) | Alias for `rosbag info`. |
| [`make validate`](./docker.md) | Alias for `cartographer_rosbag_validate`. |

## Setup

=== "uv + local"

    ```sh
    git clone git@github.com:RadarML/red-rover.git
    cd roverp
    uv sync
    ```

=== "pip + github"

    ```sh
    pip install "roverp@git+ssh://git@github.com/RadarML/red-rover.git#subdirectory=processing"
    ```

!!! warning

    `roverp` includes a number of extras, many of which are fairly heavy, and most of which you probably don't need. Avoid installing unnecessary dependencies by only installing the required extras and definitely don't `uv sync --all-extras`!.

!!! info

    If you need to run cartographer SLAM, see the [dockerized cartographer setup instructions](docker.md).

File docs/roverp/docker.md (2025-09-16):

# Cartographer - Ros - Docker

!!! abstract

    We provide a dockerized cartographer/ros stack for running a SLAM pipeline.

    - Use [`roverd rosbag`][roverd-rosbag] to convert rover data to a rosbag.
    - Run cartographer using `DATASET=... HEADLESS=true make lidar`.

## Setup

1. Ensure docker is installed:
    ```bash
    sudo snap install docker
    sudo apt-get install docker.io
    sudo systemctl enable docker
    sudo systemctl start docker
    ```

2. Install the [Nvidia Container Toolkit](https://docs.nvidia.com/datacenter/cloud-native/container-toolkit/latest/install-guide.html):
    ```bash
    distribution=$(. /etc/os-release;echo $ID$VERSION_ID)  

    curl -fsSL https://nvidia.github.io/libnvidia-container/gpgkey | sudo gpg --dearmor -o /usr/share/keyrings/nvidia-container-toolkit-keyring.gpg \
    && curl -s -L https://nvidia.github.io/libnvidia-container/stable/deb/nvidia-container-toolkit.list | \
        sed 's#deb https://#deb [signed-by=/usr/share/keyrings/nvidia-container-toolkit-keyring.gpg] https://#g' | \
        sudo tee /etc/apt/sources.list.d/nvidia-container-toolkit.list

    sudo apt-get update
    sudo apt-get install -y nvidia-docker2  
    sudo systemctl restart docker  
    ```

3. Test the install (may require a reboot, especially if `nvidia-smi` returns an error):
    ```sh
    sudo docker run --rm --gpus all nvidia/cuda:11.6.2-base-ubuntu20.04 nvidia-smi
    ```

    ??? bug "Unable to load `libnvidia-ml`"

        A common error is a failure from the `nvidia-container-cli` noting that it was unable to load `libnvidia-ml` because of `no such file or directory`. This is caused by NVIDIA hating you, and the best fix seems to be to reinstall `docker.io` (i.e. the docker engine). If that does not work, reinstall everything else as well, which will typically resolve this issue.

        *(Tianshu, 06/2024)* - I suspect this may be caused by some kind of time issue affecting certificates, triggering automated invalidations/reinstalls/etc. This behavior was seen in our demo PC, which had CMOS battery issues. The immediate symptom was total failure of the Docker/Nvidia stack; additional indications include the system time being off and docker images being re-pulled each time instead of cached.

## Usage

??? info "Manually Run Docker"

    These steps are taken care of by `make docker-run` in `collect`. Follow these steps for manual troubleshooting:

    1. Ensure that X11 forwarding is correctly set (if this does not work, you may need to activate non-local X11 forwarding).
        ```
        xhost +local:docker
        ```

    2. Run the container with the requisite NVIDIA driver arguments, the desktop env variable, and the link to the unix X11 "file". 
        ```bash
        sudo docker run -it --privileged --net=host --env=NVIDIA_VISIBLE_DEVICES=all --env=NVIDIA_DRIVER_CAPABILITIES=all --env=DISPLAY --env=QT_X11_NO_MITSHM=1 -v /tmp/.X11-unix:/tmp/.X11-unix qoschatz/cartographer_ros /bin/bash
        ```

        Mount any desired folders by adding
        ```
        -v /{full_path_to_folder}:/{full_path_in_container}
        ```
        **NOTE**: Pipe all processing results to a mounted directory to prevent outputs from being deleted when the docker container stops running.

The provided makefile assumes that there is a `data` folder (possibly symlinked) in the `red-rover/processing` directory, and that rosbags are already created using [`roverd rosbag`](../roverd/cli.md#roverd-rosbag). We provide the following commands:

- `make trajectory`: compute poses.
- `make lidar`: compute poses and output globally-aligned point clouds.
- `validate`: alias for `cartographer_rosbag_validate`.
- `info`: alias for `rosbag info`.

The following arguments are passed via environment variables:

- `DATASET`: path to dataset, relative to the `/data` directory.
- `HEADLESS`: whether to run cartographer in headless mode.

    !!! tip

        Use `HEADLESS=true` for unattended or remote operation.

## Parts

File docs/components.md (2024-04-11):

# Data Collection Setup Physical Assembly

Wiring diagram

## BOM

### Core Components
| Cost | Qty | Description |
| ---- | --- | --- |
| ~$1,000 | 1 | NUC |
| ~$8,000 | 1 | [Ouster OS0-64 or OS0-128](https://ouster.com/products/hardware/os0-lidar-sensor) |
| $449.00 | 1 | [Xsens MTi-3](https://shop.movella.com/us/product-lines/sensor-modules/products/mti-3-ahrs-development-kit) |
| $995.00 | 1 | [Black Magic Micro Studio Camera (BMMSC)](https://www.bhphotovideo.com/c/product/1787638-REG/blackmagic_design_micro_studio_camera_4k.html) |
| $299.00 | 1 | [Magewell 1080p60 USD-SDI capture card](https://www.bhphotovideo.com/c/product/1350328-REG/magewell_32070_usb_3_0_sdi_capture.html) |
| $99.0 | 1 | [Olympus Fisheye Body Cap Lens](https://www.bhphotovideo.com/c/product/1026132-REG/olympus_v325040bw000_bcl_0980_fisheye_body_cap.html)
| $28.00 | 1 | [Micro BNC to BNC cable](https://www.amazon.com/HangTon-Female-Adapter-Blackmagic-Monitor/dp/B09BJQNDNP) |
| $6.29 | 1 | [BNC Coupler](https://www.amazon.com/TLS-eagle-Coaxial-Coupler-Straight-Connector/dp/B083LZ39HM/) |
| $31.90 | 1 | [Router](https://www.amazon.com/GL-iNet-GL-AR300M16-Ext-Pre-Installed-Performance-Programmable/dp/B07794JRC5) + power supply, power cable if not included |
| $9.99 | 1 | [USB A Hub](https://www.bhphotovideo.com/c/product/1496562-REG/xcellon_usb_4311_2_slim_4_port_usb_3_1.html) |
| - | 2 | 6" Cat 5/6 Ethernet cable |
| - | 2 | 6" micro USB to USB A type 2.0 cable
| - | 1 | Power strip |
| ~$11,000 | | **Total** |

### Rig Components

| Cost | Qty | Description |
| ---- | --- | --- |
| $19.90 | 2 | [Top handles](https://www.bhphotovideo.com/c/product/1736879-REG/smallrig_1638c_top_handle_1_4_20_screws.html) |
| $29.90 | 2 | [Side handles](https://www.bhphotovideo.com/c/product/1689008-REG/smallrig_3813_mini_nato_side_handle.html) |
| $9.90 | 2 | [Mounting Rail](https://www.bhphotovideo.com/c/product/1502679-REG/smallrig_1195b_quick_release_safety_rail.html) |
| $9.90 | 1 | [Cheese Plate](https://www.bhphotovideo.com/c/product/1726809-REG/camvate_c3101_universal_cheese_plate_extension.html) |
| - | - | 1/4-20" socket cap screws |
| - | - | 1/4-20" screws button head screws |
| - | 9 | 1/4-20" nuts |
| - | - | M3 standoffs, M3 socket cap screws |
| - | - | M4 socket cap screws, M4 nuts |
| ~$140 | | **Total** |

### Optional Accessories

| Cost | Qty | Description |
| ---- | --- | --- |
| $329.99 | 2 | [External SSD](https://www.bhphotovideo.com/c/product/1595436-REG/sandisk_sdssde81_4t00_g25_4tb_extremepro_portable_ssd.html) |
| $349 | 1 | ["Lapdock" (screen + keyboard + trackpad)](https://www.amazon.com/NexDock-Touchscreen-Wireless-Portable-Compatible/dp/B0CSK2T47Q/) |

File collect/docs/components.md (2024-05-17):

# Physical Assembly / BOM

Wiring diagram

## 3D Printed Parts

| Item | Qty | Description | 
| ---- | --- | --- |
| `top-plate.stl` | 1 | Mount for Lidar, IMU |
| `front-plate.stl` | 1 | Primary vertical structure |
| `mid-plate.stl` | 1 | Connects top plate to the NUC VESA mounting plate |
| `bottom-plate.stl` | 1 | Provides structural support, and a tray to put cables in |
| `handle-bracket.stl` | 2 | Joins vertical and horizontal handles |
| `radar-cover.stl` | 1 | Protective cover for the radar; should be covered in ESD tape / other material |

## Core Components
| Cost | Qty | Description |
| ---- | --- | --- |
| ~$1,000 | 1 | NUC, with included VESA mounting plate |
| ~$8,000 | 1 | [Ouster OS0-64 or OS0-128](https://ouster.com/products/hardware/os0-lidar-sensor) |
| $449.00 | 1 | [Xsens MTi-3](https://shop.movella.com/us/product-lines/sensor-modules/products/mti-3-ahrs-development-kit) |
| $995.00 | 1 | [Black Magic Micro Studio Camera (BMMSC)](https://www.bhphotovideo.com/c/product/1787638-REG/blackmagic_design_micro_studio_camera_4k.html) |
| $299.00 | 1 | [Magewell 1080p60 USB-SDI capture card](https://www.bhphotovideo.com/c/product/1350328-REG/magewell_32070_usb_3_0_sdi_capture.html) |
| $99.0 | 1 | [Olympus Fisheye Body Cap Lens](https://www.bhphotovideo.com/c/product/1026132-REG/olympus_v325040bw000_bcl_0980_fisheye_body_cap.html)
| $28.00 | 1 | [Micro BNC to BNC cable](https://www.amazon.com/HangTon-Female-Adapter-Blackmagic-Monitor/dp/B09BJQNDNP) |
| $6.29 | 1 | [BNC Coupler](https://www.amazon.com/TLS-eagle-Coaxial-Coupler-Straight-Connector/dp/B083LZ39HM/) |
| $31.90 | 1 | [Router](https://www.amazon.com/GL-iNet-GL-AR300M16-Ext-Pre-Installed-Performance-Programmable/dp/B07794JRC5) + power supply, power cable if not included |
| $9.99 | 1 | [USB A Hub](https://www.bhphotovideo.com/c/product/1496562-REG/xcellon_usb_4311_2_slim_4_port_usb_3_1.html) |
| - | 2 | 6" Cat 5/6 Ethernet cable |
| - | 2 | 6" micro USB to USB A type 2.0 cable
| - | 1 | Power strip |
| ~$11,000 | | **Total** |

## Rig Components

| Cost | Qty | Description |
| ---- | --- | --- |
| $19.90 | 2 | [Top handles](https://www.bhphotovideo.com/c/product/1736879-REG/smallrig_1638c_top_handle_1_4_20_screws.html) |
| $29.90 | 2 | [Side handles](https://www.bhphotovideo.com/c/product/1689008-REG/smallrig_3813_mini_nato_side_handle.html) |
| $9.90 | 2 | [Mounting Rail](https://www.bhphotovideo.com/c/product/1502679-REG/smallrig_1195b_quick_release_safety_rail.html) |
| $9.90 | 1 | [Cheese Plate](https://www.bhphotovideo.com/c/product/1726809-REG/camvate_c3101_universal_cheese_plate_extension.html) |
| - | - | 1/4-20" socket cap screws, nuts |
| - | - | M3 standoffs, socket cap screws |
| - | - | M4 socket cap screws, nuts |
| ~$140 | | **Total** |

## Optional Accessories

| Cost | Qty | Description |
| ---- | --- | --- |
| $329.99 | 2 | [External SSD](https://www.bhphotovideo.com/c/product/1595436-REG/sandisk_sdssde81_4t00_g25_4tb_extremepro_portable_ssd.html) |
| $349 | 1 | ["Lapdock" (screen + keyboard + trackpad)](https://www.amazon.com/NexDock-Touchscreen-Wireless-Portable-Compatible/dp/B0CSK2T47Q/) |

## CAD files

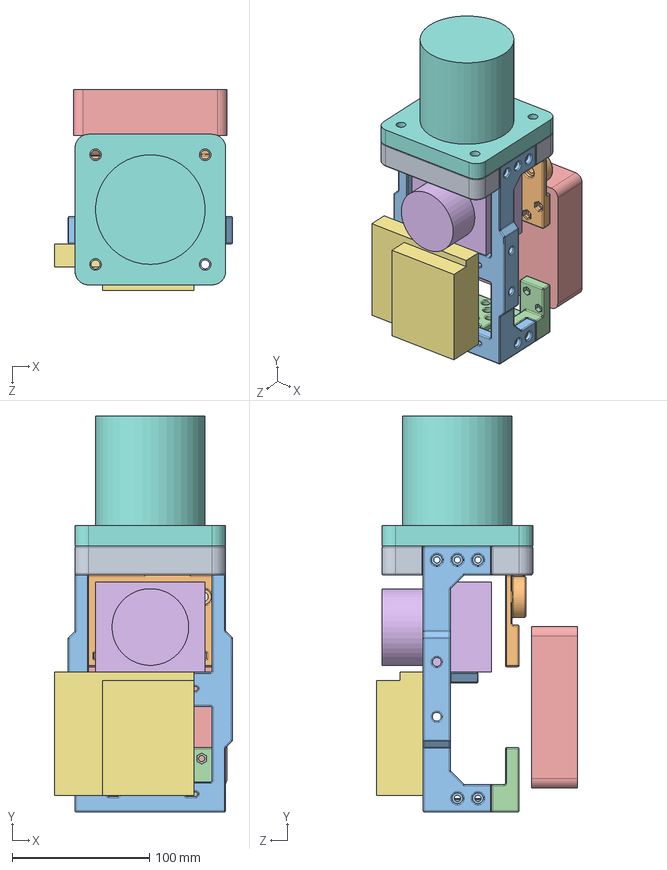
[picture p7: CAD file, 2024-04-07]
collect/parts/src/layout.SLDASM
130.0 x 289.0 x 146.6 mm
lidar
radar
camera
nuc-body
bottom-plate
front-plate
mid-plate
top-plate

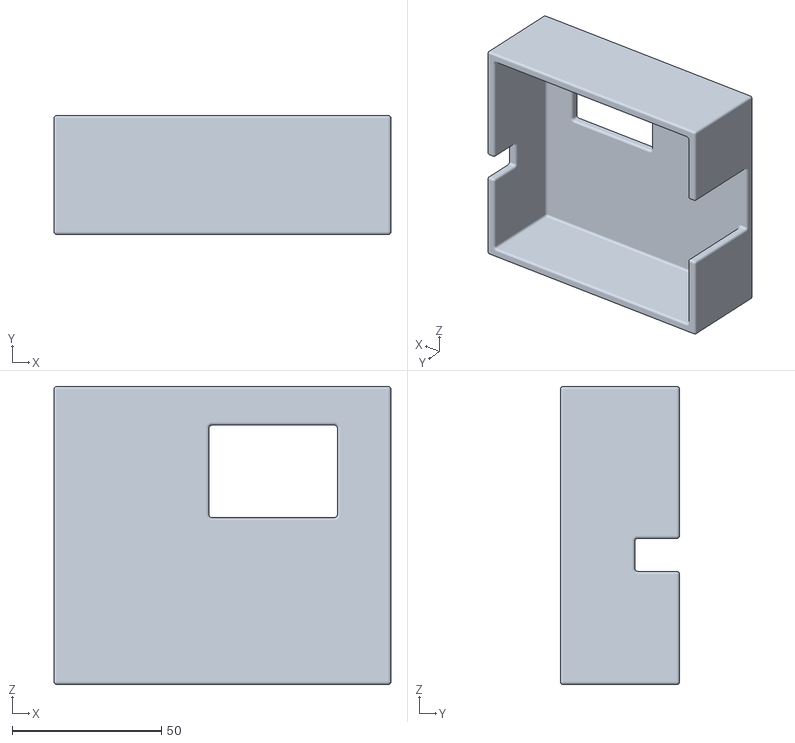
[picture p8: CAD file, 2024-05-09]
collect/parts/radar-cover.STL
113.0 x 40.0 x 100.0

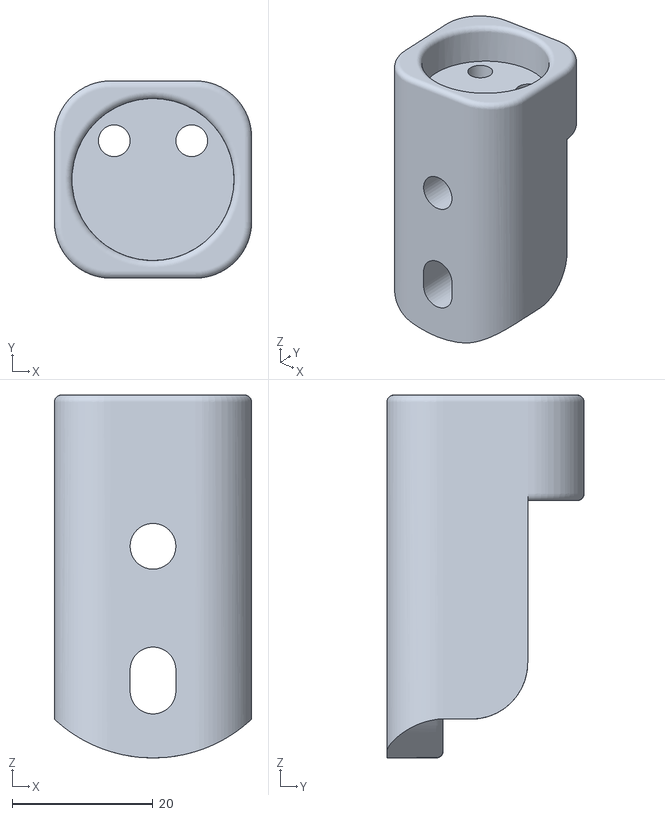
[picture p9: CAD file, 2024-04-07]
collect/parts/handle-bracket.STL
28.0 x 28.0 x 51.5

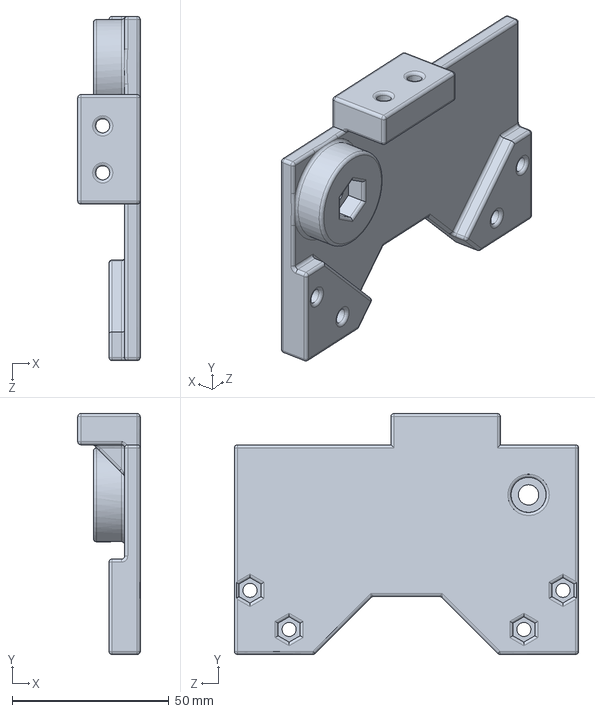
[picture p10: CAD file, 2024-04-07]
collect/parts/src/mid-plate.SLDPRT
20.0 x 77.0 x 110.0 mm

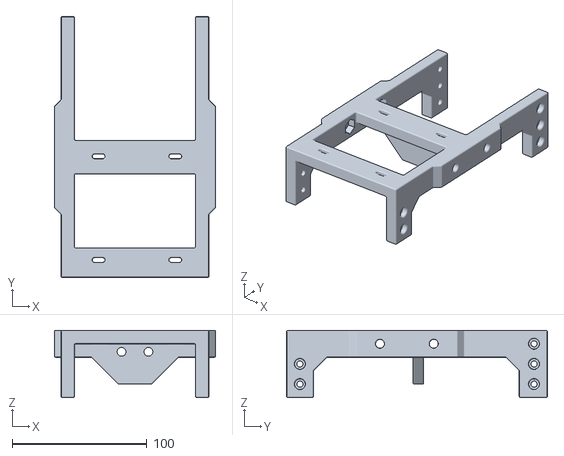
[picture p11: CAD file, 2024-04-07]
collect/parts/front-plate.STL
120.0 x 194.0 x 50.0

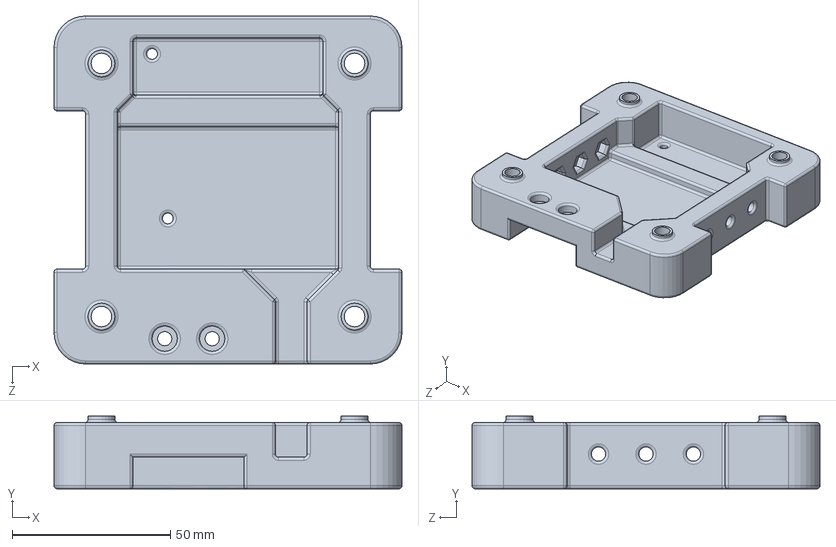
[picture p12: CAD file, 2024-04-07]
collect/parts/src/top-plate.SLDPRT
110.0 x 23.0 x 110.0 mm

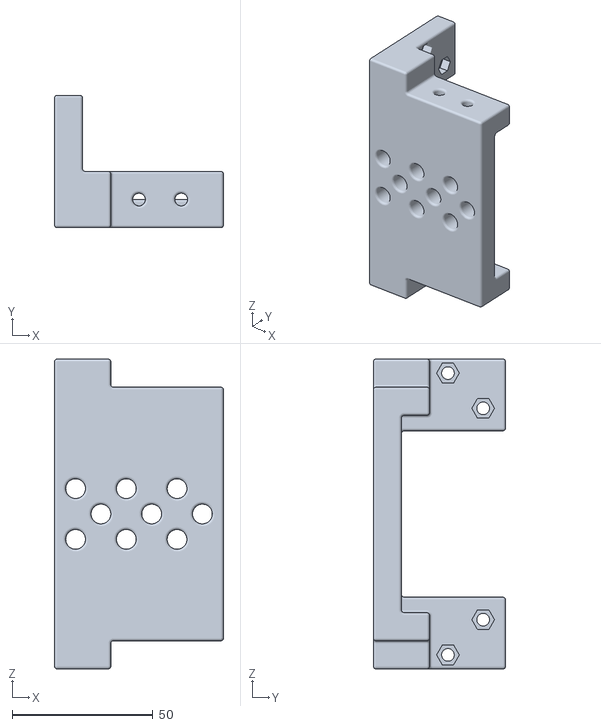
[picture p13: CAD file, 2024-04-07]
collect/parts/bottom-plate.STL
60.0 x 47.0 x 110.0

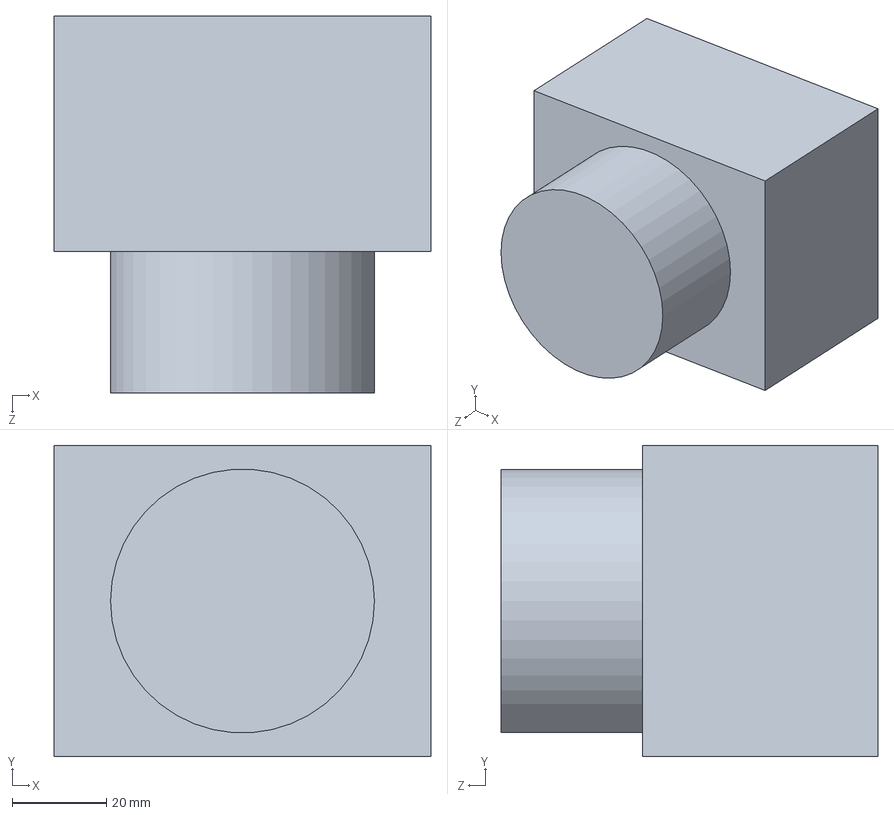
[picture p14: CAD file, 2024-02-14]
collect/parts/src/camera.SLDPRT
80.0 x 66.0 x 80.0 mm

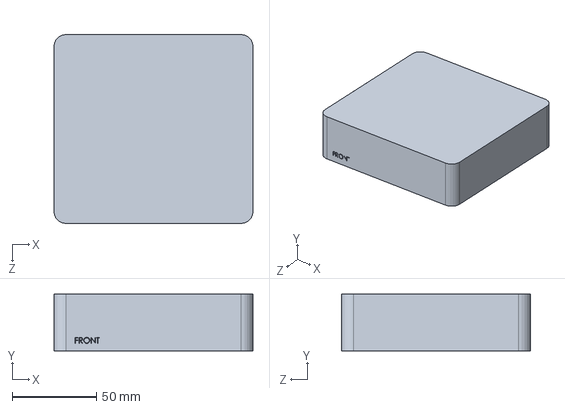
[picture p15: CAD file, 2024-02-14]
collect/parts/src/nuc-body.SLDPRT
118.0 x 33.6 x 112.0 mm

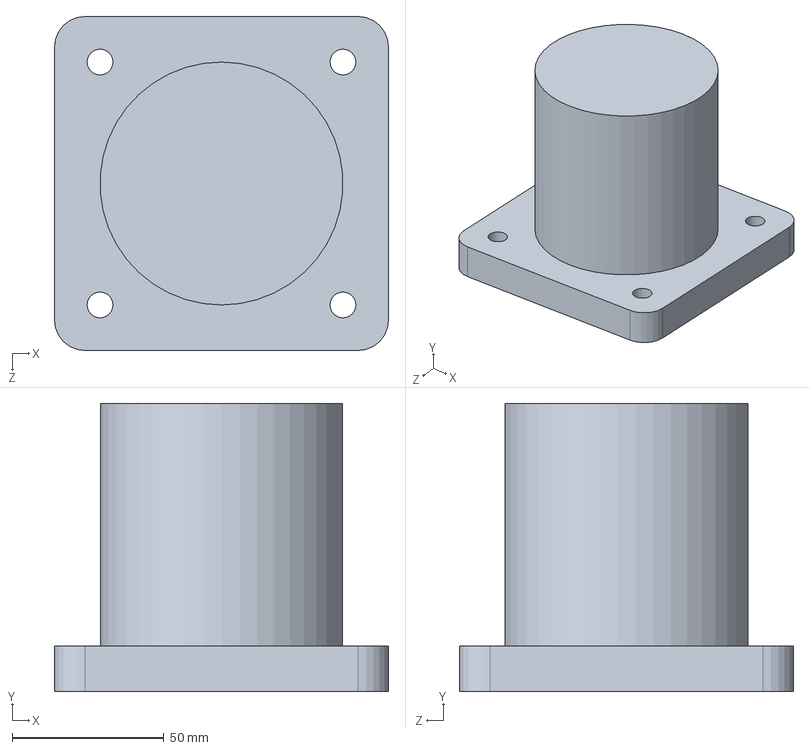
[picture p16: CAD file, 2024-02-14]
collect/parts/src/lidar.SLDPRT
110.0 x 95.0 x 110.0 mm

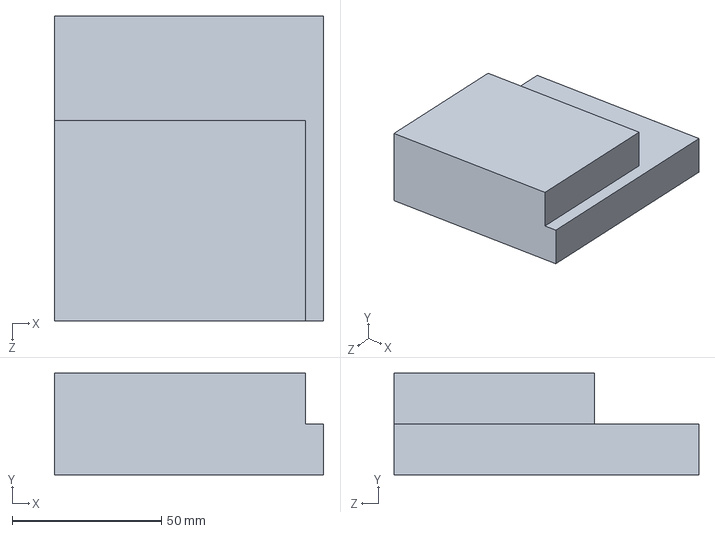
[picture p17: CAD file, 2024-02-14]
collect/parts/src/radar.SLDPRT
90.0 x 34.0 x 102.0 mm

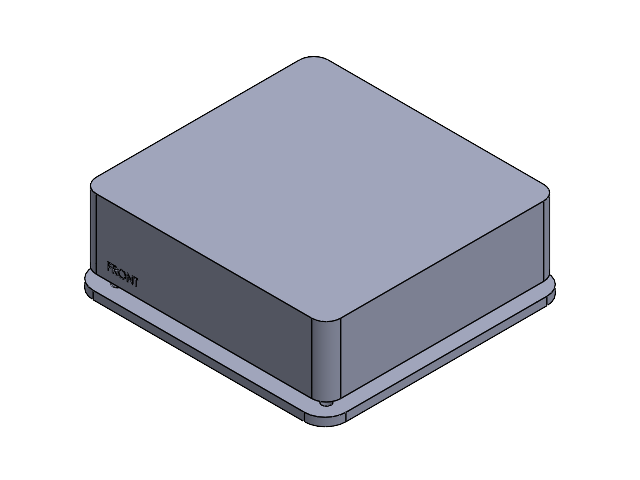
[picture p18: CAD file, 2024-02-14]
collect/parts/src/nuc.SLDASM
nuc-body
nuc-plate

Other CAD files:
collect/parts/src/radar-cover.SLDPRT
collect/parts/mid-plate.STL
collect/parts/src/handle-bracket.SLDPRT
collect/parts/src/front-plate.SLDPRT
collect/parts/src/bottom-plate.SLDPRT
collect/parts/top-plate.STL
collect/parts/src/nuc-plate.SLDPRT

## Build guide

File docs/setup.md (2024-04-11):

# Data Collection System Setup Guide

## Computer

The data collection computer uses a linux installation; we use ubuntu 22.04, though other versions should work as well.

0. Install linux.
    - If using a usb C monitor / dock to debug (e.g. the [NexDock](https://nexdock.com/explore-nexdock/)), you may need to install [DisplayLink drivers](https://www.synaptics.com/products/displaylink-graphics/downloads/ubuntu) in order to allow hot-plugging the dock.
    - Internet access is required during setup.
    - Other helpful packages:
        ```sh
        sudo apt install -y htop openssh-server git
        sudo snap install zellij --classic
        ```
    - Make sure that all ethernet interfaces are enabled (3 in total), and that the lidar interface is set to "link-local only".

1. Install dependencies:
    ```sh
    sudo add-apt-repository ppa:deadsnakes/ppa
    sudo apt install -y python3.11 python3.11-venv build-essential net-tools
    ```
    - Python 3.11 is required, since `ouster-sdk` does not work on `python3.12` as of April 2024.

2. Install `red-rover`:
    ```sh
    git clone git@github.com:WiseLabCMU/red-rover.git
    cd red-rover/collect
    make env
    ```

## Radar

A new radar needs to be configured with the following:
1. Flash firmware to the Radar (AWR1843Boost - red board), and set the DIP switch to "functional" mode.
2. Configure DIP switches on the Capture Card (DCA1000EVM - green board).

### System overview

*Red Rover* is based on the TI AWR1843Boost mmWave radar ("red board") and the DCA1000EVM capture card ("green board"). The AWR1843Boost
has a LVDS (Low Voltage Differential Signaling) "debug" port which outputs data being sent from the radar back-end to an onboard DSP processor, which can be sent to the capture card; the capture card contains a FPGA, which buffers this data and translates it into ethernet packets.

The AWR1843Boost device firmware has three code sections:
1. MSS (Master Sub-System): high-level control of the radar, which runs on an onboard ARM Cortex R4F. We use the demo firmware provided with mmWave SDK, which can be found at `demo/xwr18xx/mmwave/xwr18xx_mmw_demo.bin`.
2. DSS (DSP Sub-System): control code for the onboard DSP. This section is combined with the MSS code in the compiled code distributed with mmWave SDK.
3. RSS/BSS (Radar Sub-System / Backend Sub-System): low-level control of the radar. Uses TI proprietary code, which can be found in `firmware/radarss/xwr18xx_radarss_rprc.bin` in a mmWave SDK installation. Note that this is (probably) also included with the MSS code. 

### Flashing the AWR1843Boost

Flash the radar using [TI UniFlash](https://www.ti.com/tool/UNIFLASH); note that it seems to work most reliably on Windows. Also, obtain a copy of the `xwr18xx_mmw_demo.bin` firmware (e.g. through installing [mmWave SDK](https://www.ti.com/tool/MMWAVE-SDK)).

1. Set the radar to flash mode.
    - Find `SOP0:2` (DIP switches on the front of the radar).
    - Set the switches to `SOP0:2=101`, where 1 corresponds to the "on" position labeled on the PCB.
2. Flash using UniFlash.
    - Uniflash should automatically discover the radar.
    - Select the `demo/xwr18xx/mmwave/xwr18xx_mmw_demo.bin` image to flash.
    - Choose the serial port corresponding to the radar; the serial port should have a name/description "XDS110 Class Application/User UART (COM3)".
    - Flashing should take around 1 minute, and terminate with "Program Load completed successfully".
    - If the SOP switches are not in the correct position, flashing will fail with
        > Not able to connect to serial port. Recheck COM port selected and/or permissions
3. Set the radar to functional mode.
    - Set `SOP0:2=001`.
    - Note that mmWave studio expects the radar to be in *debug* mode (`SOP0:2=011`), so switching between Red Rover and mmWave Studio requires the position of the SOP switches to be changed. This is also why mmWave studio requires the MSS firmware to be "re-flashed" whenever the radar is rebooted.

### Configure Capture Card

Ensure that the following DIP switches are set:
- SW2.5: `SW_CONFIG`
- SW2.6: `USER_SW1` (the marked right side), unless the EEPROM is messed up from
    a misconfigured `configure_eeprom(...)` call.

The following are configured by `configure_fpga(...)` under normal operation, but can be manually set in case that isn't working:
- SW1: 16-bit mode (`16BIT_ON`, `14BIT_OFF`, `12BIT_OFF`).
- SW2.1: `LVDS_CAPTURE`
- SW2.2: `ETH_STREAM`
- SW2.3: `AR1642_MODE` (2-lane LVDS)
- SW2.4: `RAW_MODE`
- SW2.5: `HW_CONFIG`

### Hardware Troubleshooting

The [TI mmWave Demo Visualizer](https://dev.ti.com/gallery/view/mmwave/mmWave_Demo_Visualizer/ver/3.6.0/) is a good way to validate hardware functionality, and uses the same firmware that Red Rover uses.

Possible faults:
- An error is returned on the console in the Demo Visualizer: there may be a hardware fault. It should be raised with a line number in `mss_main.c`; the error case (e.g. `RL_RF_AE_CPUFAULT_SB`) should reveal what general type of fault it is.
- When powered on, the capture card error lights should all come on for ~1sec, then turn off again. If this does not occur, the FPGA may be dead.

## Camera

Plug a HDMI cable into a monitor in order to change the settings. Select the following using the buttons on the front:
- Focus: set to "optimum focus" - move the focus lever into the detent at the bottom.
- Gain: 18db (for typical indoors lighting; change based on lighting conditions).
- SDI output: 1080p60

Note that the HDMI menu overlay is not shown on the SDI output.

## IMU

Install [MT Manager](https://www.movella.com/support/software-documentation), and connect the Xsens MTi-3 IMU via the development board. Select the following:
- Orientation: Euler Angles; Floating Point 32-bit; 100Hz
- Inertial data: Rate of Turn, Acceleration; Floating Point 32-bit; 100Hz

## Lidar

Should work out-of-the-box. Make sure that an IP is assigned to the lidar in the management page.

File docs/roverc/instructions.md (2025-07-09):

# Data Collection: Step by Step

!!! info

    This guide assumes you have already assembled, installed, and configured `red-rover`. See the [assembly](./assembly.md) and [software setup & sensor configuration](./setup.md) guides if you have not done so already (or this has not been done for you).

## Physical checks

1. Ensure that the protective cover is removed from the radar.
2. The radar, lidar, camera, and computer should be plugged in.

    !!! danger

        The radar and lidar power supplies use the same-sized barrel jack. Ensure that the radar and lidar power cables are not crossed, since **24V power supplied to the Lidar will fry the radar**.

3. The router should be plugged in to the exposed ethernet cable at the backpack end of the cable snake, along with power. The ethernet cable should be connected to the `LAN` port.

4. Plug an external SSD into the data collection rig using one of the USB C ports on the back of the data collection computer. The SSD should fit in the gap between the camera and the rear plate of the data collection rig.

## Power on

1. Turn on the AC battery by pressing the power button, followed by the `AC` button.

2. Insert the battery into the backpack.

    - Plug the power strip with attached power bricks (which may or may not be inside a cable management box) into one of the battery's AC outlets.

    !!! warning

        Ensure that any power buttons are facing outwards (i.e. away from your back) to prevent accidentally pressing the button during data collection.

3. Verify that the Radar, Lidar, and Camera have turned on automatically.

    !!! info "Expected Behavior"

        - Several lights (red and green) should appear on the radar.
        - The lidar should begin to spin after a few seconds; this will be evident as a subtle vibration/hum when running in 10Hz mode and a more aggressive vibration when running at 20Hz. This mode will match what the Lidar was previously configured to use, which may be different from the configuration which you intend to use.
        - The tally light on the front of the camera will turn on. The tally light will always be white (changing its color to red requires access to a special API via SDI in, HDMI, or ethernet which we do not use).

4. Turn on the computer using the power button on the right.

    !!! info "Expected Behavior"
    
        - A white LED under the power button will illuminate when turned on.

## Configure data collection.

1. Connect a display, keyboard, and mouse (or equivalent, e.g. a ["lapdock"](https://www.amazon.com/NexDock-Touchscreen-Wireless-Portable-Compatible/dp/B0CSK2T47Q/)) to the computer. Log in (the computer should be set to auto-log-in without a password).

2. Open a terminal. Select the desired config, configure, and start the server:

    ```
    export ROVER_CFG=dart.yaml
    sudo -E make config
    make
    ```

    !!! warning

        The config file (`dart.yaml` here) must match the physical hardware used:

        - `lidar/interface` and `radar/interface` should match the ethernet interfaces used to communicate with  the lidar and radar respectively (i.e. in `ifconfig`)
        - `lidar/beams` should match the number of physical beams on the lidar (i.e. `beams: 128` for a 128-beam Ouster lidar).
        - `imu/args/port` and `radar/args/radar/port` should match the serial ports that the IMU and radar mount to, respectively, though these ports should be consistent between systems provided no additional serial devices are plugged in.

## Connect the controller

1. Connect the controller device to the data collection rig's wifi network.

    - Any device with a web browser can be used as the controller. A smart phone is suggested.
    - The router may take a minute or more to boot when powered on.
    - The network name and password should be labeled on the router; the name should also match the name of the data collection rig, which should be on the front of the main rig.

2. Connect the web browser to `{name}.local:5000` where `{name}` is the name of the data collection computer.

    !!! tip

        This should be written on the data collection computer, and should match the name of the data collection rig.

## Collect data

!!! tip

    Do a dry run of the data collection process before unplugging to go collect data!

1. Select the target drive / output location.

    - By default, a `data` option is always included; this saves data to the local disk in the current working directory. External drives will show up as `/data-a`, `/data-b`, etc.
    - External drives should mount automatically.
    - Options are only loaded on page load; if you plug in an external drive after loading the web app, refresh the page.

    !!! tip
    
        If an external drive still does not show up, verify that the drive has mounted automatically in `/media/rover/...` using the display/keyboard/terminal.

2. **(optional)** Provide a trace name.

    - Use the text input to set a name that the recorded trace will be saved as.
    - If left blank, will be named after the current timestamp in `YYYY-MM-DD.HH-MM-SS` format.

3. In the web app, press the `start` button.
    
    !!! info "Expected Behavior"

        - Text should begin to scroll on all four sections of the web app; the frequency and utilization of data collection for each sensor are regularly logged.

    !!! info

        Blue messages indicate normal information.
    
    !!! warning
    
        Yellow messages indicate warnings.

        * The IMU usually gives an `invalid checksum` warning when starting data collection; if this only occurs once, it can be ignored.
        * The radar may give a `missing packets` warning from time to time. If this occurs infrequently (once every few blue status messages, i.e. no more than a few times per minute), it can be ignored. Missing packet warnings are observed to be correlated with certain locations, and perhaps temperature/humidity; the exact cause is not known.
        * If the data collection frequency drops below 99% of the expected frequency, a warning is logged. This can be ignored if intermittent.

    !!! failure "Error"

        Red messages indicate errors. **Upon receiving an error, you should immediately stop data collection until the cause is identified**.

        - If you attempt to start data collection when one is already running, or start a data collection with a name which is already used, you will receive an error.
        - If you attempt to stop data collection when no data collection is running, you will also receive an error.
        - Any other errors are likely system and/or hardware problems. If a full reboot (turn off computer, unplug the battery, and return to step 0.) does not fix the problem, please report this.
        - If the data collection frequency drops below 90% of the expected frequency, an error is logged. If this happens outside of initialization (e.g. not in the first few messages), please report this.

4. Press stop.

    !!! info "Expected Behavior"

        Each section should stop collecting data.
    
    !!! note
    
        If you reload the page while data collection is active, the `STOP` button will be greyed out, since the web app does not save its state. In this case, press `START`; this will cause an error, which can be ignored. The `STOP` button will then be enabled.

## Clean up

1. Ensure that data collection is not active.

2. Plug the monitor/keyboard/mouse back in. Kill the server (with `ctrl+C`), then shut down the computer with `sudo shutdown now`.

3. Unplug the power strip from the battery.

    - Return the battery to its charger.
    - If using a shared controller phone, please return the phone to its charger as well.

4. Replace the protective cover on the radar.

## Troubleshooting

If some data types (especially Lidar) are not being collected as expected:

- Check all cables for loose connections or damaged connectors.
- Reboot the data collection computer.
- Reboot the rig (by turning off the computer, and unpowering all sensors, e.g. by unplugging the root power strip).

For radar-related issues:

- See the [`xwr` troubleshooting documentation](https://radarml.github.io/xwr/#troubleshooting).

If the camera is not coming through at full rate:

- Check for damaged/kinked cables and loose connections.
- Remove all of the camera-related cables and connectors from the internal cavity, lay them out flat, then test.

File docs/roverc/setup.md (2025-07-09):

# Software Setup and Sensor Configuration

## Computer

The data collection computer uses a linux installation; we use ubuntu 22.04, though other versions should work as well.

0. Install linux.

    !!! info

        If using a usb C monitor / dock to debug (e.g. the [NexDock](https://nexdock.com/explore-nexdock/)), you may need to install [DisplayLink drivers](https://www.synaptics.com/products/displaylink-graphics/downloads/ubuntu) in order to allow hot-plugging the dock.

    - Internet access is required during setup.
    - Other helpful packages:
        ```sh
        sudo apt install -y htop openssh-server git
        sudo snap install zellij --classic
        ```
    - Make sure that all ethernet interfaces are enabled (3 in total), and that the lidar interface is set to "link-local only".

1. Install [uv](https://github.com/astral-sh/uv):

    ```sh
    curl -LsSf https://astral.sh/uv/install.sh | sh
    # or
    wget -qO- https://astral.sh/uv/install.sh | sh
    ```

2. Install `red-rover`:
    ```sh
    git clone git@github.com:RadarML/red-rover.git
    cd red-rover/collect
    uv sync
    ```

## Sensors

**Radar**: Follow the setup instructions described in the [XWR documentation](https://radarml.github.io/xwr/setup/#awr1843boost).

**Camera**: Plug a HDMI cable into a monitor in order to change the settings. Select the following using the buttons on the front:

- Focus: set to "optimum focus" - move the focus lever into the detent at the bottom.
- Gain: 18db (for typical indoors lighting; change based on lighting conditions).
- SDI output: 1080p60

    !!! note

        The HDMI menu overlay is not shown on the SDI output.

**IMU**: Install [MT Manager](https://www.movella.com/support/software-documentation), and connect the Xsens MTi-3 IMU via the development board. Select the following:

- Orientation: Euler Angles; Floating Point 32-bit; 100Hz
- Inertial data: Rate of Turn, Acceleration; Floating Point 32-bit; 100Hz

**Lidar**: Should work out-of-the-box.

!!! warning

    Make sure that an IP is assigned to the lidar in the [web management page](https://static.ouster.dev/sensor-docs/image_route1/image_route2/connecting/connecting-to-sensors.html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).

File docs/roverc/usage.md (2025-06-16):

# Manual Operation

!!! info

    These steps may be useful for debugging and/or troubleshooting.

## Makefile + Zellij

0. Set configuration file.
    ```sh
    ROVER_CFG=`realpath config/dart.yaml`
    ```

1. Configure interfaces.
    ```sh
    sudo -E make config
    ```

    !!! info

        We must use `-E` in order to pass through environment variables (i.e. `ROVER_CFG`). You can also use `sudo ROVER_CFG=path/to/cfg.yaml make config`.

2. Start data collection processes.
    ```sh
    make
    ```
    
    !!! warning
    
        This requires/uses [zellij](https://zellij.dev/):
        ```sh
        sudo snap install zellij --classic
        ```

3. Run data collection
    ```sh
    make start
    make stop
    ```

4. Clean up and kill data collection processes by quitting zellij (`ctrl` + `q`).

## Fully Manual

1. Configure interfaces:
    - Set the radar interface to a static IP:
        ```sh
        sudo ifconfig [radar/interface] 192.168.33.30 netmask 255.255.255.0
        ```
    - Set the socket receive buffer size:
        ```sh
        echo [radar/args/capture/socket_buffer] | sudo tee /proc/sys/net/core/rmem_max
        ```
    - Set Lidar interface to link-local:
        ```
        sudo ip addr add 169.254.11.103/16 dev [lidar/interface]
        ```
    - Set IMU, radar serial port permissions:
        ```sh
        sudo chmod 666 /dev/ttyACM0
        sudo chmod 666 /dev/ttyUSB0
        ```

2. Launch data collection processes (in the background, in separate terminals, in `screen`, etc.):
    ```sh
    screen -dm bash -c "./env/bin/python cli.py run --config [config.yaml] --sensor radar"
    screen -dm bash -c "./env/bin/python cli.py run --config [config.yaml] --sensor camera"
    screen -dm bash -c "./env/bin/python cli.py run --config [config.yaml] --sensor lidar"
    screen -dm bash -c "./env/bin/python cli.py run --config [config.yaml] --sensor imu"
    ```

3. Run data collection
    ```
    ./env/bin/python cli.py start -c [config.yaml] -p [output/path]
    ./env/bin/python cli.py stop
    ```

4. Terminate each data collection process
    ```
    ./env/bin/python cli.py exit -c [config.yaml]
    ```

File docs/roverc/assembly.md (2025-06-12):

# Hardware Assembly

<div class="grid" markdown>

Front

Back

</div>

## Bill of Materials

!!! warning

    Listed prices are as of August 2024, and may be out of date.

    Prices for minor items (fasteners, connectors, cables, etc) are also omitted.

!!! info

    Building `red-rover` requires a 3D printer with a print bed size of at least 200x120x50mm (LxWxH); we used a Bambu Lab X1C with Bambu Red PLA Basic filament.

??? quote "Electrical"

    **Core Components**

    | Cost | Qty | Description |
    | ---- | --- | ----------- |
    | $299.00 | 1 | [TI AWR1843Boost](https://www.ti.com/tool/AWR1843BOOST) Radar + 5V3A barrel jack power supply if not included |
    | $599.00 | 1 | [TI DCA1000EVM](https://www.ti.com/tool/DCA1000EVM) Capture Card |
    | ~$1,000 | 1 | NUC, with included VESA mounting plate |
    | ~$8,000-$12,000 | 1 | [Ouster OS0-64 or OS0-128](https://ouster.com/products/hardware/os0-lidar-sensor) |
    | $449.00 | 1 | [Xsens MTi-3](https://shop.movella.com/us/product-lines/sensor-modules/products/mti-3-ahrs-development-kit) |
    | $995.00 | 1 | [Black Magic Micro Studio Camera (BMMSC)](https://www.bhphotovideo.com/c/product/1787638-REG/blackmagic_design_micro_studio_camera_4k.html) |
    | $299.00 | 1 | [Magewell 1080p60 USB-SDI capture card](https://www.bhphotovideo.com/c/product/1350328-REG/magewell_32070_usb_3_0_sdi_capture.html) |
    | $99.0 | 1 | [Olympus Fisheye Body Cap Lens](https://www.bhphotovideo.com/c/product/1026132-REG/olympus_v325040bw000_bcl_0980_fisheye_body_cap.html)
    | $28.00 | 1 | [Micro BNC to BNC cable](https://www.amazon.com/HangTon-Female-Adapter-Blackmagic-Monitor/dp/B09BJQNDNP) |
    | $6.29 | 1 | [BNC Coupler](https://www.amazon.com/TLS-eagle-Coaxial-Coupler-Straight-Connector/dp/B083LZ39HM/) |
    | $31.90 | 1 | [Router](https://www.amazon.com/GL-iNet-GL-AR300M16-Ext-Pre-Installed-Performance-Programmable/dp/B07794JRC5) + power supply, power cable if not included |
    | $9.99 | 1 | [USB A Hub](https://www.bhphotovideo.com/c/product/1496562-REG/xcellon_usb_4311_2_slim_4_port_usb_3_1.html) |
    | - | 1 | AC battery bank; should be able to supply >200W. |
    | - | 2 | 6" Cat 5/6 Ethernet cable |
    | - | 2 | 6" micro USB to USB A type 2.0 cable
    | - | 1 | Power strip |

    **Optional Accessories**

    | Cost | Qty | Description |
    | ---- | --- | ----------- |
    | $329.99 | 2 | [External SSD](https://www.bhphotovideo.com/c/product/1595436-REG/sandisk_sdssde81_4t00_g25_4tb_extremepro_portable_ssd.html) |
    | $349 | 1 | ["Lapdock" (screen + keyboard + trackpad)](https://www.amazon.com/NexDock-Touchscreen-Wireless-Portable-Compatible/dp/B0CSK2T47Q/) |

??? quote "Mechanical"

    **3D Printed Parts**

    | Item | Qty | Description | 
    | ---- | --- | ----------- |
    | `top-plate.stl` | 1 | Mount for Lidar, IMU |
    | `front-plate.stl` | 1 | Primary vertical structure |
    | `mid-plate.stl` | 1 | Connects top plate to the NUC VESA mounting plate |
    | `bottom-plate.stl` | 1 | Provides structural support, and a tray to put cables in |
    | `handle-bracket.stl` | 2 | Joins vertical and horizontal handles |
    | `radar-cover.stl` | 1 | Protective cover for the radar; should be covered in ESD tape / other material |

    **COTS Parts**

    | Cost   | Qty | Description |
    | ------ | --- | ----------- |
    | $19.90 | 2   | [Top handles](https://www.bhphotovideo.com/c/product/1736879-REG/smallrig_1638c_top_handle_1_4_20_screws.html) |
    | $29.90 | 2   | [Side handles](https://www.bhphotovideo.com/c/product/1689008-REG/smallrig_3813_mini_nato_side_handle.html) |
    | $9.90  | 2   | [Mounting Rail](https://www.bhphotovideo.com/c/product/1502679-REG/smallrig_1195b_quick_release_safety_rail.html) |
    | -      | 1   | 1/4-20 Ball Head |
    | -      | 1   | Phone Tripod Mount |

??? quote "Fasteners"

    | Qty | Description |
    | --- | ----------- |
    | 9   | 1/4-20 Nut |
    | 8   | 1/4-20 x 15mm socket cap |
    | 3   | 1/4-20 x 15mm round head |
    | 4   | 1/4-20 x 25mm round head |
    | 20  | M4 nut |
    | 18  | M4 lock washer |
    | 8   | M4 x 10mm socket cap |
    | 4   | M4 x 12mm socket cap |
    | 12  | M4 x 16mm socket cap |
    | 2   | M3 x 6mm female-female standoff |
    | 2   | M3 x 6mm male-female standoff |
    | 4   | M3 x 15mm female-female standoff (included with AWR1843Boost) |
    | 4   | M3 x 15mm male-female standoff |
    | 4   | M3 x 5mm round head (included with AWR1843Boost) |
    | 6   | M3 x 8mm socket cap |

## Sub-assemblies

### Handles (2x)

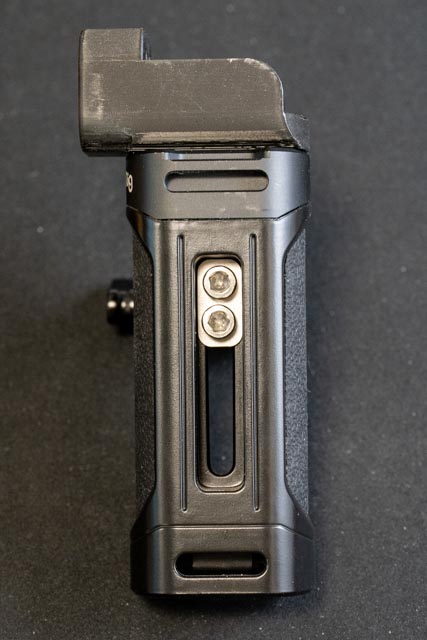
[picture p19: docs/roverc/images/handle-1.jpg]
Handle Subassembly, Side

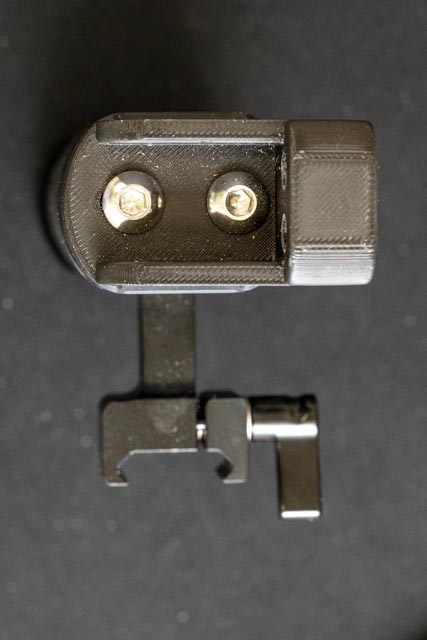
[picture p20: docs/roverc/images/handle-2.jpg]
Handle Subassembly, Top

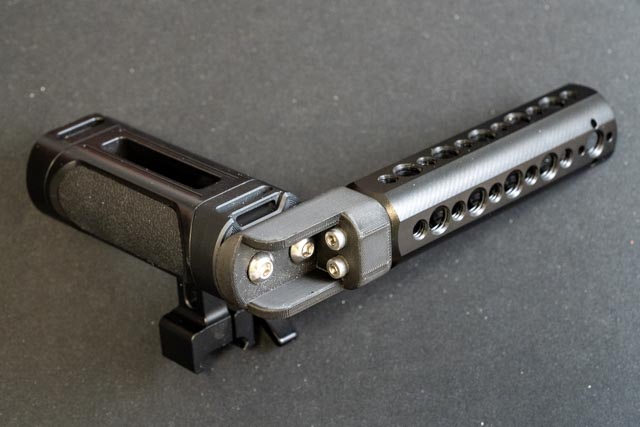
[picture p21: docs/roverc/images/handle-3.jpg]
Handle Subassembly, Perspective


1. Assemble the side handles according to the manufacturer's instructions by attaching the NATO rail mount.

2. Attach a `handle-bracket.stl` to the top of each side handle using `2x 1/4-20x15mm round head screws` each.

3. Attach the top handles to the handle bracket using `2x M4x12mm screws` each.

!!! info

    Viewed relative to the top handle facing towards you, one handle (for the left side side) should have the adjustment knob facing forward and the mounting rail facing right, while the other (for the right side) should have the adjustment knob facing forward and the mounting rail facing left.

    <div class="grid" markdown>

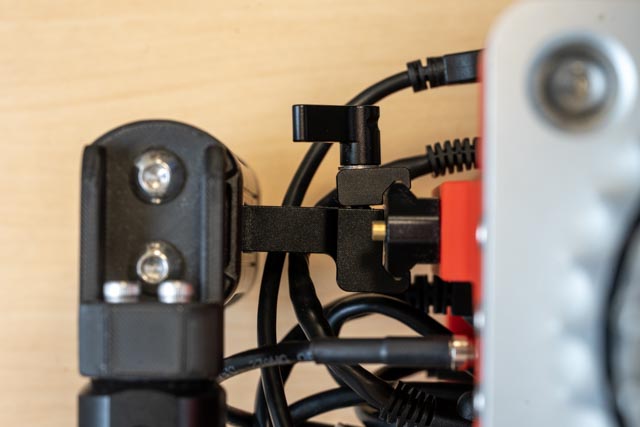
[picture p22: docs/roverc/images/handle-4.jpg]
Left
    

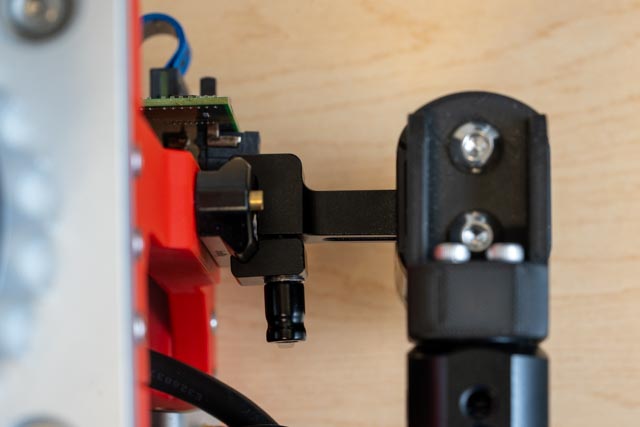
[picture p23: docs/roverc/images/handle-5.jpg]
Right
    

    </div>

### Top Subassembly

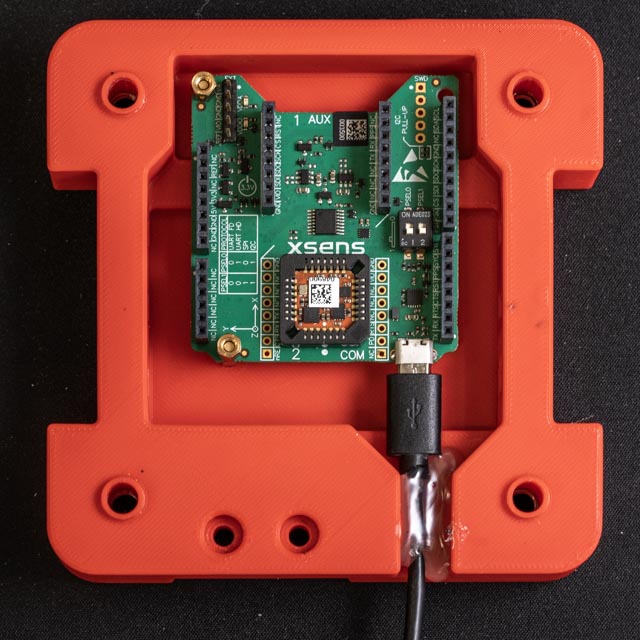
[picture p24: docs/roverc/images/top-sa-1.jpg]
Top Subassembly, Top

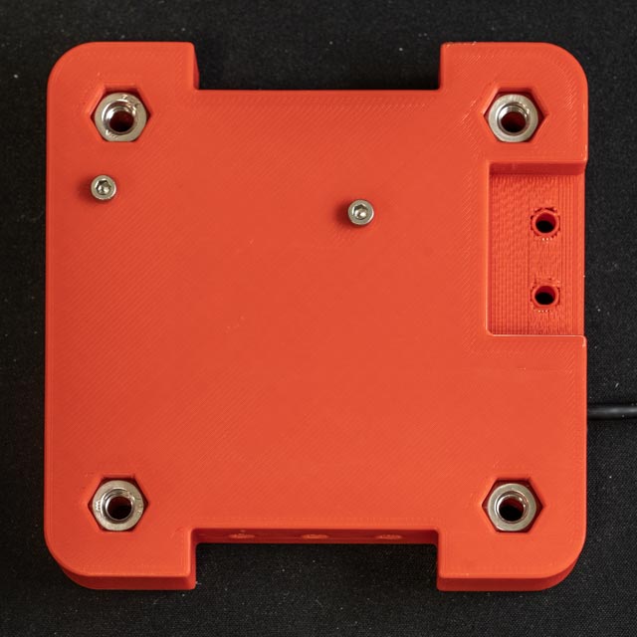
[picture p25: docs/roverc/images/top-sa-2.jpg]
Top Subassembly, Bottom


1. Attach `2x M3x6mm F/M` standoffs to the small holes in the `top-plate.stl` using `2x M3x8mm screws`.

2. Press-fit `4x 1/4-20 nuts` and `6x M4 nuts` to the matching holes.

    !!! info

        If the M4 nuts will not stay in, don't attach the IMU or fit the nuts until final assembly.

3. Plug in a Micro USB cable, and attach the `Xsens MTi-3 IMU` using `2x M3x6mm F/F` standoffs. Hot-glue the USB connector to the top plate

    !!! info

        You can use `M3 nuts` instead, but small standoffs are usually easier to work with and either tighten by hand, or using a small socket driver.

### Rear Subassembly

<div class="grid" markdown>

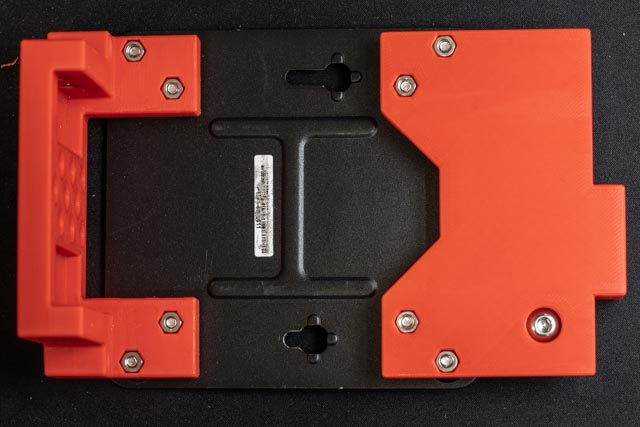
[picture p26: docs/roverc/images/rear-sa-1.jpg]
Rear Subassembly, Front


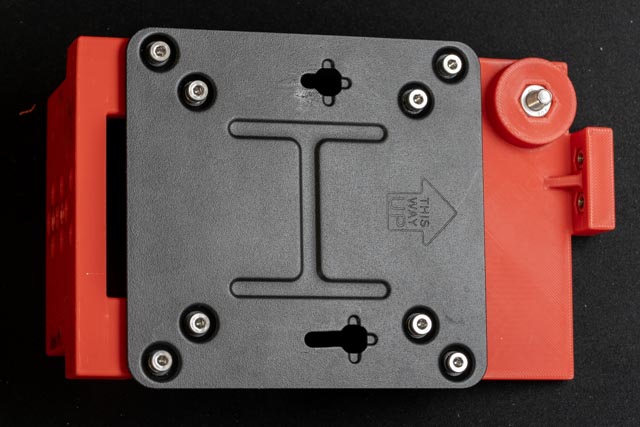
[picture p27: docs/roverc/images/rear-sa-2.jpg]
Rear Subassembly, Back


</div>

1. Attach the `bottom-plate.stl` to the mounting plate included with the NUC using `4x M4 nuts`, `4x M4x10mm screws`, and `4x M4 lock washers`.

2. Attach the `top-plate.stl` to the mounting plate included with the NUC using `4x M4 nuts`, `4x M4x10mm screws`, and `4x M4 lock washers`.

    !!! warning

        Make sure the orientation of the mounting plate is correct! The "This way up" arrow should point towards the `top-plate.stl`, and the screw heads should be inset into the mounting hole divots.

3. Press-fit `2x M4 nuts` into the matching holes on the `top-plate.stl`.

4. Insert a `1/4-20 nut` into the matching hole on the `top-plate.stl`, and screw a `1/4-20x15mm round head screw` into the nut from the other side. The screw head should be fully flush in the recess.

### Front Subassembly

<div class="grid" markdown>

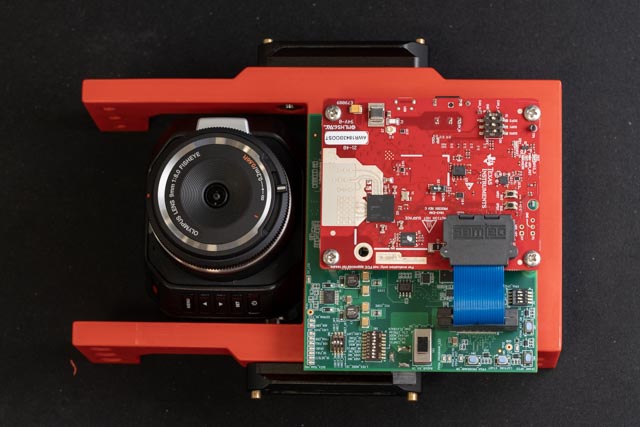
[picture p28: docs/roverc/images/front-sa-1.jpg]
Front Subassembly, Front


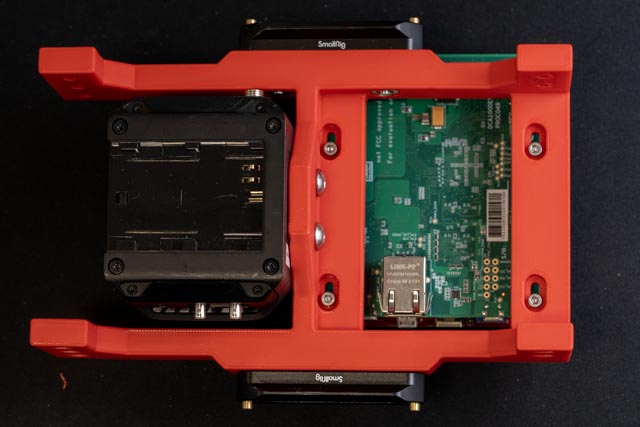
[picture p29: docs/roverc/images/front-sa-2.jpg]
Front Subassembly, Back


</div>

1. Attach the two NATO rails to each side of the `front-plate.stl` using `4x 1/4-20 nuts` and `4x 1/4-20x18mm socket cap screws`.

2. Attach `4x M3x15mm M/F` standoffs to the slotted holes using `4x M3x8mm screws`.

3. Fit the `DCA1000EVM` capture card to the standoffs.

4. Screw `4x M3x15mm F/F` standoffs (included with the AWR1843Boost) on the exposed standoffs, mounting the capture card in place.

5. Fit the `AWR1843Boost` radar to the standoffs from the previous step, securing it in place with `4x M3x5mm screws` (included with the AWR1843Boost).

6. Attach the `Black Magic Micro Studio Camera` to the `front-plate.stl` using `2x 1/4-20x15mm round head screws`.

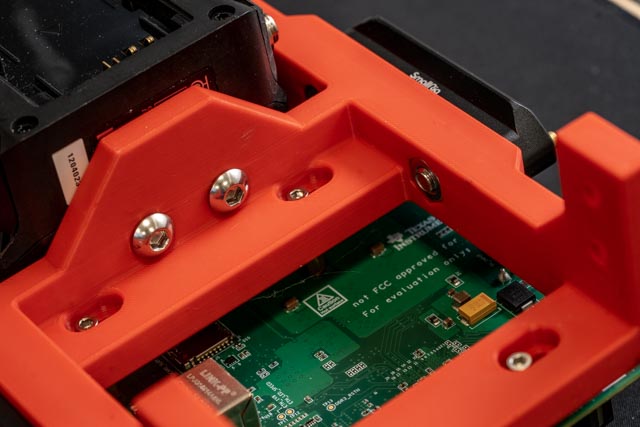
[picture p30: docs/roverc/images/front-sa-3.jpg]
Front Subassembly, Detail
    

## Final assembly

### Combine Subassemblies

1. Attach the rear subassembly to the front subassembly using `4x M4x16mm screws`, `4x M4 nuts`, and `4x M4 lock washers`.

2. Attach the top subassembly to the rear subassembly using `2x M4x16mm screws`, and attach the top subassembly to the front subassembly using `6x M4x16mm screws` and `6x M4 lock washers`.

    !!! info

        If you did not press-fit any nuts or install the IMU earlier, do so now.

3. Attach the `Ouster OS0 Lidar` to the top subassembly using `4x 1/4-20x25mm screws`.

    !!! warning

        The previous step blocks access to the rear lidar mounting nuts. Make sure they did not fall out!

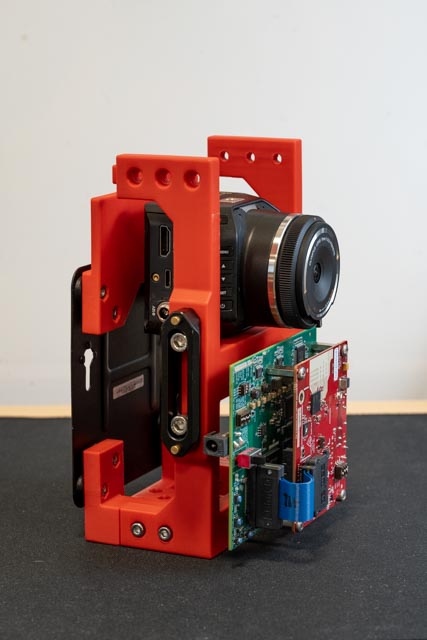
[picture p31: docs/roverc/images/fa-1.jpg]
    
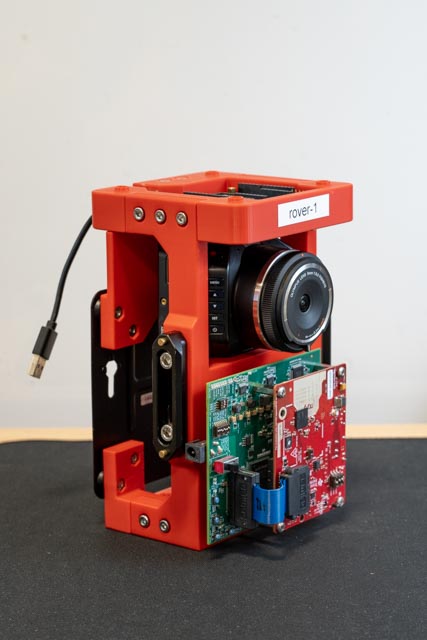
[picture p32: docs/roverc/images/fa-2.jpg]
    
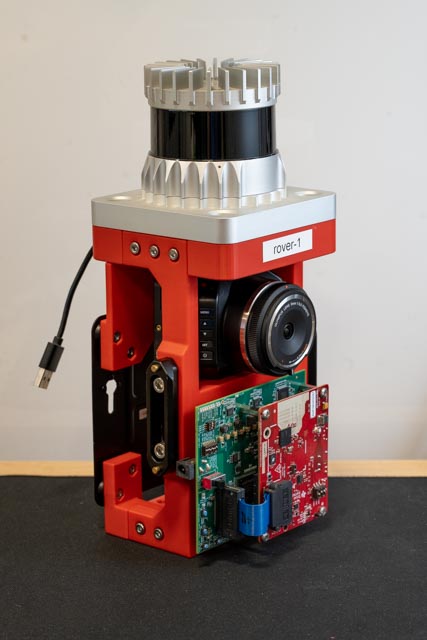
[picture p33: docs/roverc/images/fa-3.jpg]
    

4. Mount the NUC to its mounting plate following the manufacturer's instructions. The front of the NUC should be facing the right side of the rig.

5. Use double-sided adhesive or velcro adhesive strips to attach a USB hub and USB ethernet adapter to the NUC.

6. Screw `1/4-20 ball mount` to the exposed 1/4-20 screw on the rear subassembly, and attach the phone tripod mount to the ball mount.

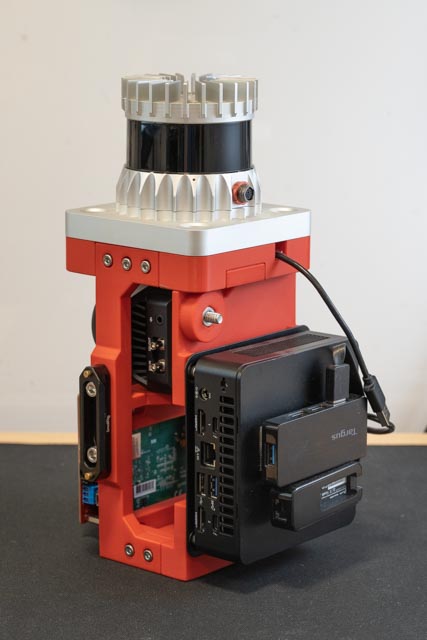
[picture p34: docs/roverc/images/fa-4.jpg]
    
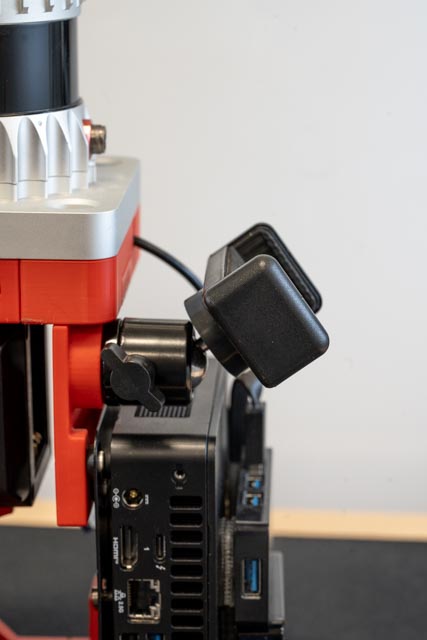
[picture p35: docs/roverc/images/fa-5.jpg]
    

### Connect Wiring

!!! note

    Most wiring and interfaces should fit in the cavity underneath the camera.

Wiring diagram

1. Lidar

    - The `Ouster OS0 Lidar` should be connected to its interface box.
    - The interface box should be connected to the NUC using a short ethernet patch cable.

2. Radar

    - The `AWR1843Boost` should be connected to the rear USB hub using a USB 2.0 Micro B to A cable.
    - The `DCA1000EVM` should be connected to a USB ethernet adapter using a short ethernet patch cable. The USB ethernet adapter should be plugged into the front of the NUC.

3. Camera

    - The `Black Magic Micro Studio Camera` should be connected to the `Magewell USB Capture SDI Gen 2`.
    - The capture card should be connected to a USB 3.0 Type A port at the back of the NUC using the included (spec-violating) USB 3.0 Type A to Type A cable.

4. Other

    - The `Xsens MTi-3 IMU` should be connected to the rear USB hub using a USB 2.0 Micro B to A cable.
    - The USB ethernet adapter attached to the NUC should be plugged into the USB hub.
    - The USB hub should be plugged into the front of the NUC.

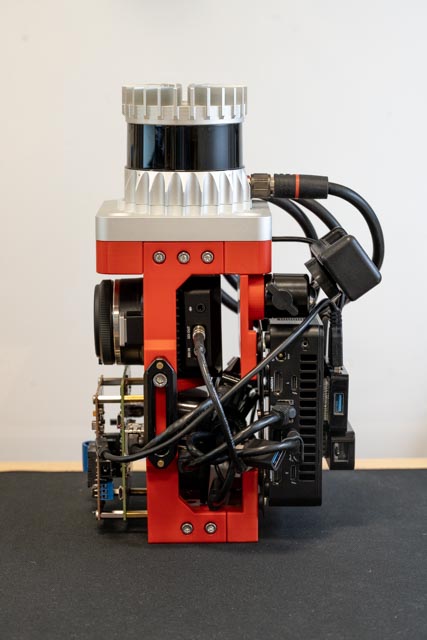
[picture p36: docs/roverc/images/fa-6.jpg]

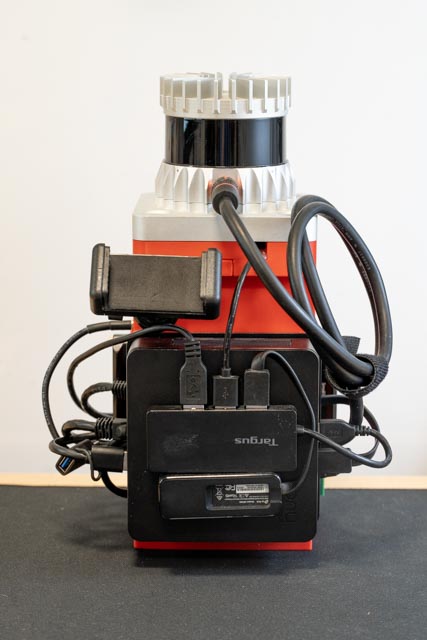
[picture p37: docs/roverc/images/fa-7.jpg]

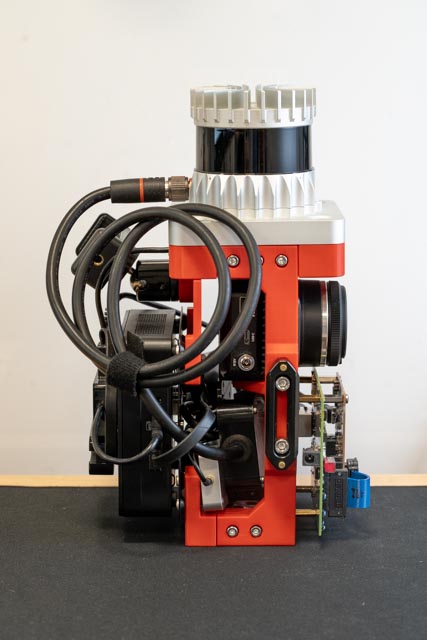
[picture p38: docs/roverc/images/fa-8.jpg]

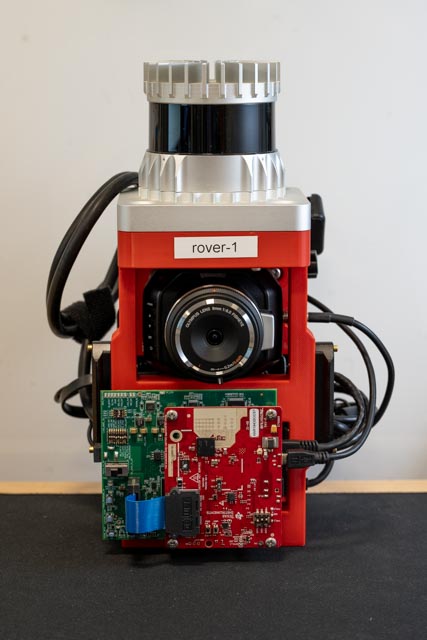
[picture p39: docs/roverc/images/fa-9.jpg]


### Complete Setup

1. Plug in the power supplies for the radar, lidar, camera, and NUC.

    - Each power supply should be connected to a power strip attached to the AC battery bank.

    !!! danger

        The radar and lidar power supplies use the same-sized barrel jack. Ensure that the radar and lidar power cables are not crossed, since **24V power supplied to the Lidar will fry the radar**.

2. Plug in a ethernet cable to the USB ethernet adapter attached to the back of the NUC.

    - The Ethernet adapter should be plugged into the wireless control router.

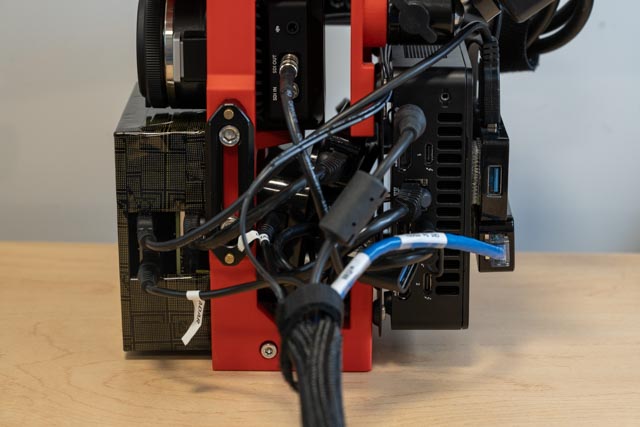
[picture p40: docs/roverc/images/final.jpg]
    

3. Assemble support pack.

    - The support pack should include the AC battery bank, power strip, power converters, and wireless router along with its power supply.

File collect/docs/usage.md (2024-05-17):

# Usage

## UI Operation

1. Specify configuration file, configure system, and start server:
    ```sh
    export ROVER_CFG=dart.yaml
    sudo -E make config
    make
    ```

2. Connect to the web server; the server address should be `{computer_name}.local:5000`.

3. Select the output path.
    - Dropdown: output location (locally in the `./data` folder or in an external drive)
    - Text input: output dataset name. If blank, will be named after the current timestamp in `YYYY-MM-DD.HH-MM-SS` format.

4. Use the start/stop buttons.
    - The **Start** button will be disabled after starting data collection until the **Stop** button is pressed. This status may not be accurate if there are multiple connections or the page is refreshed.
    - The **Stop** button will be greyed out if the page thinks no data collection sessions are active, but the `stop` command will still be sent even if clicked in case a desync has occured since there is no harm in attempting to stop when there is no active session.

## CLI Operation

0. Set configuration file.
    ```sh
    ROVER_CFG=`realpath dart.yaml`
    ```

1. Configure interfaces.
    ```sh
    sudo -E make config
    ```
    - **NOTE**: we must use `-E` in order to pass through environment variables (i.e. `ROVER_CFG`). You can also use `sudo ROVER_CFG=path/to/cfg.yaml make config`.

2. Start data collection processes.
    ```sh
    make
    ```
    - **NOTE**: this requires/uses [zellij](https://zellij.dev/).

3. Run data collection
    ```sh
    make start
    make stop
    ```

4. Clean up and kill data collection processes by quitting zellij (`ctrl` + `q`).

## Manual Operation

1. Configure interfaces:
    - Set the radar interface to a static IP:
        ```sh
        sudo ifconfig [radar/interface] 192.168.33.30 netmask 255.255.255.0
        ```
    - Set the socket receive buffer size:
        ```sh
        echo [radar/args/capture/socket_buffer] | sudo tee /proc/sys/net/core/rmem_max
        ```
    - Set Lidar interface to link-local:
        ```
        sudo ip addr add 169.254.11.103/16 dev [lidar/interface]
        ```
    - Set IMU, radar serial port permissions:
        ```sh
        sudo chmod 666 /dev/ttyACM0
        sudo chmod 666 /dev/ttyUSB0
        ```

2. Launch data collection processes (in the background, in separate terminals, in `screen`, etc.):
    ```sh
    screen -dm bash -c "./env/bin/python collect.py run -c [config.yaml] -s radar"
    screen -dm bash -c "./env/bin/python collect.py run -c [config.yaml] -s camera"
    screen -dm bash -c "./env/bin/python collect.py run -c [config.yaml] -s lidar"
    screen -dm bash -c "./env/bin/python collect.py run -c [config.yaml] -s imu"
    ```

3. Run data collection
    ```
    ./env/bin/python collect.py start -c [config.yaml] -p [output/path]
    ./env/bin/python collect.py stop
    ```

4. Terminate each data collection process
    ```
    ./env/bin/python collect.py exit -c [config.yaml]
    ```

## Troubleshooting

If some data types (especially Lidar) are not being collected as expected:
- Reboot the data collection computer.
- Reboot the rig (by turning off the computer, and unpowering all sensors, e.g. by unplugging the root power strip).

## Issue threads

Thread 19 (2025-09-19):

`RadarMetadata` missing from `roverd.sensors` export

thetianshuhuang, 2025-09-19:
`RadarMetadata` should be exposed by `roverd.sensors`,  but is not included in the `__init__.py`.

Closed 2025-09-27.

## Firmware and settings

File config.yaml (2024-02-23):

lidar:
  script: "lidar.py"
  args:
    addr: null
    port_lidar: 7502
    port_imu: 7503
    fps: 10.0
    height: 64
imu:
  script: "imu.py"
  args:
    port: /dev/ttyUSB0
    baudrate: 115200
camera:
  script: "camera.py"
  args:
    idx: 0
    width: 1920
    height: 1080
    fps: 60.0

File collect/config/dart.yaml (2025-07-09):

lidar:
  type: lidar
  interface: enp86s0
  args:
    addr: null
    port_lidar: 7502
    port_imu: 7503
    mode: 1024x20
    beams: 64
imu:
  type: imu
  args:
    port: /dev/ttyUSB0
    baudrate: 115200
camera:
  type: camera
  args:
    idx: 0
    width: 1920
    height: 1080
    fps: 30.0
radar:
  type: radar
  interface: enx207bd2bd84d3
  comment: "DART, indoor"
  args:
    radar:
      device: AWR1843
      port: /dev/ttyACM0
      frequency: 77.0
      idle_time: 331.0
      adc_start_time: 5.7
      ramp_end_time: 59.00
      tx_start_time: 1.0
      freq_slope: 67.012
      adc_samples: 128
      sample_rate: 2500
      frame_length: 128
      frame_period: 100.0
    capture:
      sys_ip: 192.168.33.30
      fpga_ip: 192.168.33.180
      data_port: 4098
      config_port: 4096
      timeout: 1.0
      socket_buffer: 4194304
      delay: 200.0

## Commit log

2024-02-14 Add part files for 3D printed rig
    [bottom-plate.SLDPRT, bottom-plate.STL, camera.SLDPRT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]
2024-02-16 Started from-scratch rewrite of lidar + new camera implementation
    [MTi_1.stl, MTi_1.urdf, MTi_10.urdf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]
2024-02-18 Properly configure # radar beams + wiring diagram
2024-02-23 first test of api on red board
2024-02-23 fixed serial printing bug
2024-02-23 Add IMU sensor data collection
2024-02-23 Fixed IMU -> low latency mode; misc type cleanup
    [common.py, imu.py, lidar.py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]
2024-02-24 fixed awr_api bugs on red board
2024-02-24 More tweaks / integration fixes
    [camera.py, common.py, imu.py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]
2024-02-26 Update mechanical design
    [layout.SLDASM, mid-plate.SLDPRT, mid-plate.STL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]
2024-02-27 More config tweaks + stability improvements
    [common.py, config.yaml, radar.py]
2024-02-27 Change to busy-wait for data socket
2024-02-27 Packet drop issue characterized and fixed via increased buffer size
    [config.yaml, radar.py]
2024-02-29 Cartographer working
    [red-rover.urdf]
2024-03-06 Add video rendering for debug; added lidar output for rover1 baselinesx
    [red-rover.urdf]
2024-03-08 Misc refactoring/cleanup + switched RDA to DRA order
2024-03-08 Add 2, 3, antenna configuration option
2024-03-08 Update config + discovered new limitation on frame size
2024-03-20 Add Lidar-based simulation via arrow + other misc improvements
2024-04-04 Update assembly files
    [bottom-plate.SLDPRT, bottom-plate.STL, front-plate.SLDPRT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]
2024-04-10 Update config to fetch $LIDAR_IP automatically
2024-04-10 Fix LIDAR_IP command
2024-04-12 Changed compression level to 0 for lidar + docs improvements
2024-04-12 Change default align to lidar as "left" sensor
2024-04-23 Misc bugfixes
    [red-rover.urdf]
2024-05-09 Reorganized + added protective cover
    [bottom-plate.SLDPRT, bottom-plate.STL, camera.SLDPRT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]
2024-05-17 Add collect documentation builder + switch to google-style docstringso
2024-05-17 Added processing sphinx documentation + misc organization
    [bottom-plate.SLDPRT, bottom-plate.STL, camera.SLDPRT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]
2024-06-26 Add calibration code, nerfstudio conversion code
2024-07-31 Increase socket buffer size
2024-07-31 New timestamp error model to handle frame drops + make cartographer auto-close when done
2024-08-01 Upgraded metadata handling: moved export to regex, --require_pose option in align, --threshold option in sensorpose
2024-08-28 Added semantic segmentation pipeline + switched to new roverd library
2024-09-04 Misc bugfixes (endianness semantics + max(C) instead of max(T))
    [common.py, imu_api.py]
2024-12-10 Switched elevation FFT to same convention as deep-radar + cleaned up unused notebook outputs
2025-06-10 Add stats (tss) + docs and other fixes
    [camera.py, lidar.py, radar.py]
2025-06-12 Add assembly guide and images
2025-06-15 Switch to bytearray->memoryview->readinto to allow passing to pytorch without a copy
2025-06-16 Working new collect stack (after a few bugfixes)
    [lidar.py]
2025-07-04 Bugfixes: type fix list -> Sequence + correction for XWRRadar default should be auto
    [camera.py, radar.py]
2025-07-06 Add pose sensor, dataset/trace splitting
2025-07-09 Changed all sensors and data types to be natively temporal
2025-09-08 Explicitly specify sensors to upload + upload _radar/pose
2025-09-22 Add missing exports to roverd.sensors (#19)
2025-11-25 Add calibration
2025-12-11 Additional test case for video downsampling via high level API

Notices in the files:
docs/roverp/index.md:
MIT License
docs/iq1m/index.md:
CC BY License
